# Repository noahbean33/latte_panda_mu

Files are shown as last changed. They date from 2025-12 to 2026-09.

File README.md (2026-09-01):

# LattePanda Mu Carrier Board

A custom 4-layer carrier board for the **LattePanda Mu** x86 compute module (Intel N100 / N305), designed in KiCad. The module supplies the CPU, RAM and storage; this board turns its 260-pin edge connector into real-world I/O with Gigabit Ethernet, HDMI, USB 2.0/3.0, two M.2 slots, GPIO/I²C/UART headers, PWM fan control, and a dual-input power supply.

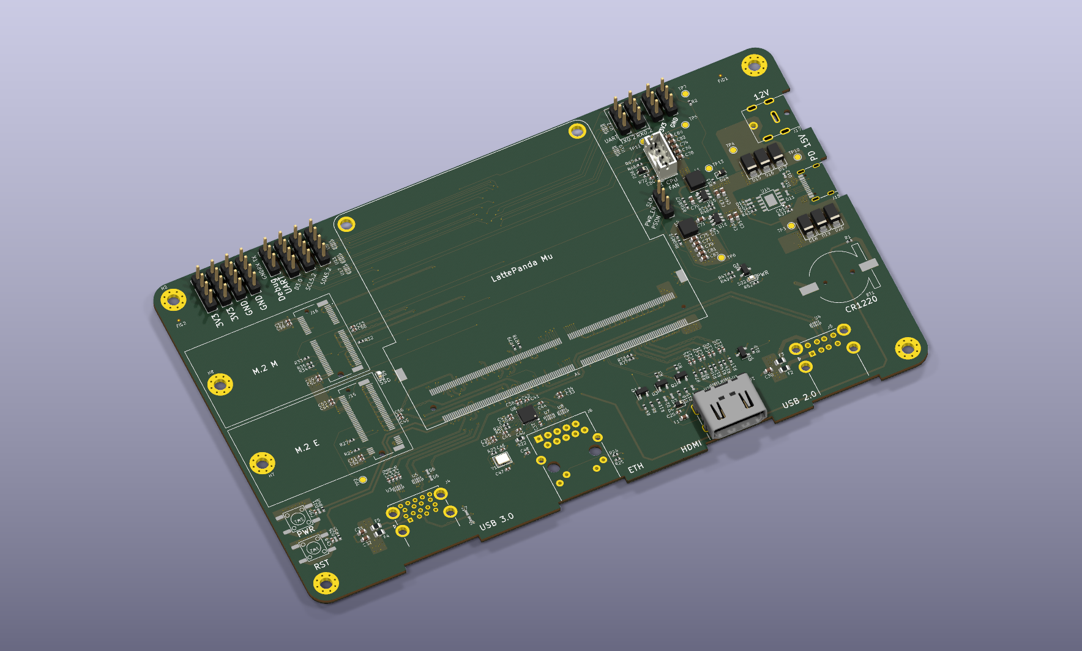
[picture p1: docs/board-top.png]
Top view of the carrier board


*3D render from the current KiCad source*

---

## Board at a glance

| | |
|---|---|
| **Outline** | 170.1 × 100.1 mm, 8 mounting holes (M3 + M2), 2 fiducials |
| **Stackup** | 4 layers — `F.Cu` / `In1.GND` / `In2.PWR` / `B.Cu`, 1.606 mm, FR4 εr 4.5, impedance-controlled |
| **Power in** | 12 V barrel jack **or** USB-C PD (CH224K negotiates 15 V) — diode-ORed onto a common `VDC` rail |
| **Rails** | `VDC` → 2× LM2734X buck → **+5V**, **+3V3**; **+1V0** local to the Ethernet PHY; **+BATT** from a CR1220 for the module RTC |
| **Ethernet** | RTL8111H-CG GbE controller on a PCIe x1 link, RJ45 with integrated magnetics |
| **Display** | HDMI Type-A, driven from the module's `DDI_B` port |
| **USB** | 2× USB 3.0 Type-A (stacked), 2× USB 2.0 Type-A (stacked), 1× USB-C (**power only**) |
| **M.2** | M-key (PCIe x1, NVMe) + E-key (PCIe x1 + USB 2.0, Wi-Fi/BT) |
| **Expansion** | PCIe x4 slot — fully designed, **not populated** in this revision |
| **Misc** | 4-pin PWM/tach fan header, power + reset buttons, debug UART, 13 test points (10 populated) |
| **Size of the job** | 217 placed footprints, 354 nets, 680 vias, 9 hierarchical sheets |

Full parts list: [`LattePandaMu_carrier_custom.csv`](LattePandaMu_carrier_custom.csv).

---

## Where the high-speed lanes go

| Module resource | Spent on | Notes |
|---|---|---|
| `HSIO_0` TX/RX | USB 3.0 port 1 SuperSpeed | TX AC-coupled (C26/C27) |
| `HSIO_1` TX/RX | USB 3.0 port 2 SuperSpeed | TX AC-coupled (C28/C29) |
| `HSIO_2` + `REFCLK0` | M.2 **M**-key — PCIe x1 | TX AC-coupled (C49/C50) |
| `HSIO_3` + `REFCLK3` | M.2 **E**-key — PCIe x1 | TX AC-coupled (C55/C56) |
| Dedicated GbE PCIe pair + clock | RTL8111H | AC-coupled (C38/C39/C42/C43) |
| `HSIO_8` – `HSIO_11` | *reserved* for the PCIe x4 slot | currently unrouted (slot is DNP) |
| `DDI_B_TX0..3` | HDMI TMDS | AC-coupled, ESD arrays U1/U2 |
| `USB2_P1/2/3/5` | 4× USB Type-A ports | |
| `USB2_P7` | M.2 E-key | Bluetooth on a combo card |
| `USB2_P4/6/8` | unused | |

AC coupling appears on **TX pairs only** — the far-end receiver provides its own caps, per PCIe and USB 3.0 convention.

---

## Schematic hierarchy

| Sheet | File | Contents |
|---|---|---|
| LattePanda Module | [`LattePanda_Module.kicad_sch`](LattePanda_Module.kicad_sch) | 260-pin module connector and all lane fan-out |
| Power Supply | [`psu.kicad_sch`](psu.kicad_sch) | DC jack, USB-C PD (CH224K), ORing, 2× buck, power sequencing |
| Gigabit Ethernet | [`ethernet.kicad_sch`](ethernet.kicad_sch) | RTL8111H, 25 MHz crystal, MDI pairs, RJ45 |
| HDMI | [`hdmi.kicad_sch`](hdmi.kicad_sch) | DDI_B → TMDS, ESD protection, fused +5 V |
| USB 2.0 & 3.0 | [`usb_2_3.kicad_sch`](usb_2_3.kicad_sch) | Stacked A-connectors, per-port fusing, ESD |
| M.2 M Key | [`m2_em_key.kicad_sch`](m2_em_key.kicad_sch) | Both the M-key and E-key sockets |
| PCIe x4 | [`pciex4.kicad_sch`](pciex4.kicad_sch) | x4 slot + AC caps — all DNP |
| GPIO | [`gpio.kicad_sch`](gpio.kicad_sch) | 4× I²C, 3× UART, 4× GPP headers |
| Fan | [`fan.kicad_sch`](fan.kicad_sch) | 4-pin PWM fan header and drive |

---

## Design rules

Net classes are pattern-assigned in the project file, so a net gets the right geometry from its name:

| Class | Applies to | Track / diff-pair geometry |
|---|---|---|
| `100Ω` | `*MDI*` (Ethernet magnetics side) | 0.144 mm width / 0.100 mm gap |
| `90Ω` | USB 2.0/3.0, PCIe, HSIO, TMDS, REFCLK | 0.199 mm width / 0.099 mm gap |
| `PWR` | `*+*V*` rails | 0.3 mm track, 0.2 mm clearance |
| `Default` | everything else | 0.15 mm track |

Board minimums: 0.14 mm track, 0.2 mm via / 0.2 mm hole, 0.1 mm annular ring, 0.2 mm copper-to-edge.

---

## Repository layout

```
.
├── LattePandaMu_carrier_custom.kicad_pro   # open this in KiCad
├── LattePandaMu_carrier_custom.kicad_pcb   # 4-layer layout
├── LattePandaMu_carrier_custom.kicad_sch   # root hierarchical schematic
├── LattePandaMu_carrier_custom.kicad_dru   # custom design rules
├── LattePandaMu_carrier_custom.csv         # BOM export
├── *.kicad_sch                             # sub-sheets (table above)
├── sym-lib-table / fp-lib-table            # project-scoped, ${KIPRJMOD}-relative
├── Libraries/                              # custom symbols and footprints
├── Assembly/                               # pick-and-place (top / bottom)
├── docs/                                   # renders and documentation images
```

---

## Getting started

1. Install **KiCad 10 or newer** <https://www.kicad.org/download/>.
2. Clone the repository:
   ```bash
   git clone https://github.com/noahbean33/latte_panda_mu.git
   ```
3. Open `LattePandaMu_carrier_custom.kicad_pro`. The library tables are `${KIPRJMOD}`-relative, so `Libraries/` is picked up with no global install.
4. Descend into sub-sheets from the root schematic; open the PCB editor for the layout.

Re-run the checks yourself:

```bash
kicad-cli sch erc --format json -o erc.json LattePandaMu_carrier_custom.kicad_sch
```

```bash
kicad-cli pcb drc --format json -o drc.json LattePandaMu_carrier_custom.kicad_pcb
```

---

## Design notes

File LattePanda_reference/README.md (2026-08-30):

# LattePanda Mu Carrier Development Resources

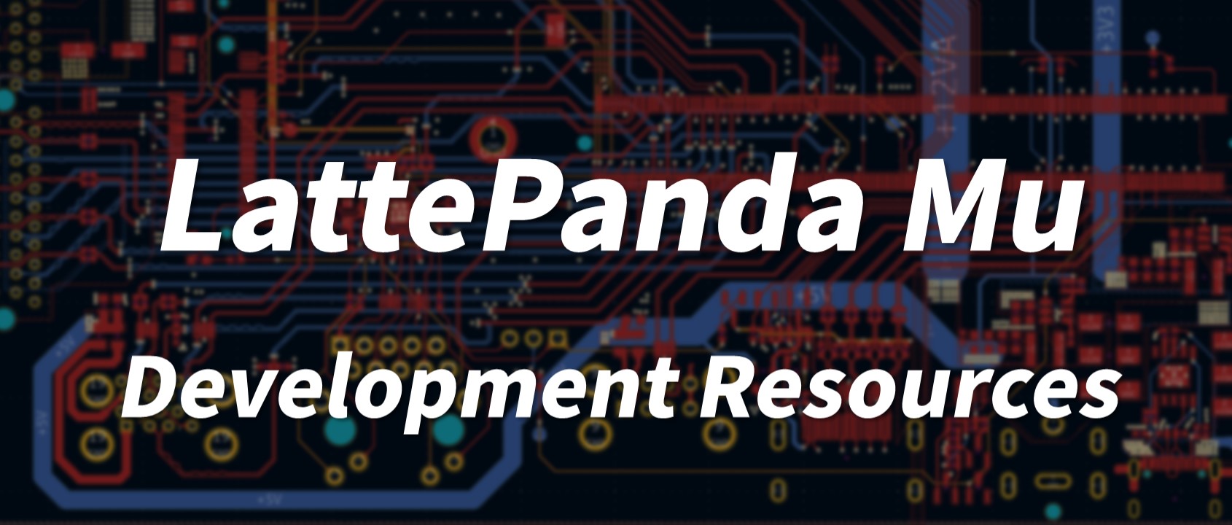
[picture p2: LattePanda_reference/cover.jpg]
cover


Welcome to the repository of development resources for the LattePanda Mu. With its extensive array of interfaces, you can craft your very own carrier board. While we have provided several reference designs to spark your creativity, a myriad of exciting possibilities awaits your discovery. This repository will be continuously updated to support the development of your personalized carrier board solutions.

## Documentation

- [**LattePanda Mu Compute Module User Guide**](https://docs.lattepanda.com/content/mu_edition/introduction/)

- [**Carrier Board Hardware Design Guide**](https://docs.lattepanda.com/content/mu_edition/design_guide_foreword/)

- [**Carrier Board User Guide**](https://docs.lattepanda.com/content/mu_edition/lite_carrier/)

- [**LattePanda Website**](https://www.lattepanda.com/)

- [**Join our Discord**](https://discord.gg/RkSvc9g7eU)

## Resource Directory

- **Electricals**: This includes pin descriptions, symbols and footprint libraries, project templates, and example projects.

- **Mechanicals**: This section provides dimensional drawings and 3D models of the LattePanda Mu, its heatsink, and other accessories.

- **Software**: BIOS, firmware, drivers, and other related software resources.

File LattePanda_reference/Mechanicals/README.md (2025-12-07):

# Model Files

Models of LattePanda Mu and related accessories for structural design use.

The STEP format models are large in size, hence they are compressed using 7-Zip. Please use [7-Zip](https://www.7-zip.org/) or another compatible software to extract the `.7z` files before use.

## Files

- [**LattePanda_Mu_Dimension_Drawing.pdf**](./LattePanda_Mu_Dimension_Drawing.pdf): LattePanda Mu Dimensional Drawing, PDF format

- [**LattePanda_Mu_Dimension_Drawing.dxf**](./LattePanda_Mu_Dimension_Drawing.dxf): LattePanda Mu Dimensional Drawing, DXF format

- [**LattePanda_Mu.step.7z**](./LattePanda_Mu.step.7z): Contains only the basic model of LattePanda Mu.

- [**LattePanda_Mu_H8.0_Horizontal.step.7z**](./LattePanda_Mu_H8.0_Horizontal.step.7z): Includes the model of LattePanda Mu and the H8.0 horizontal connector, which is the standard mounting method for LattePanda Mu, and can be used directly in PCB design as an enclosure model.

- [**LattePanda_Mu_H4.0_Horizontal.step.7z**](./LattePanda_Mu_H4.0_Horizontal.step.7z): Includes the model of LattePanda Mu and the H4.0 horizontal connector, and can be used directly in PCB design as an enclosure model.

- [**FIT0982-Thin-Heatsink.step.7z**](./FIT0982-Thin-Heatsink.step.7z): Thin heatsink only, without Mu.

- [**FIT0989-Fanless-Heatsink.step.7z**](./FIT0989-Fanless-Heatsink.step.7z): Fanless heatsink only, without Mu.

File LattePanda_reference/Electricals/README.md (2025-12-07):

# Electronic Design Resources

## Files

- Examples: Sample projects

- Libraries: Symbol and footprint libraries for LattePanda Mu

- Pinouts: All pin definitions for LattePanda Mu

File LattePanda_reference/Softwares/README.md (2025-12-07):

# Software Resources

Within this repository, you will find a range of software resources specifically related to the LattePanda Mu, including BIOS updates, firmware, and a variety of drivers.

Please be aware that this repository is dedicated to providing materials relevant to the LattePanda Mu. For firmware and drivers related to expansion carrier boards, refer to the respective carrier board documentation pages for more details.

## Resource Categories

- **BIOS**: Contains stable and beta BIOS updates officially supported, as well as related tools.

- **Drivers**: Drivers and related descriptions.

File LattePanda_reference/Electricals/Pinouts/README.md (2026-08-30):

# Pinouts

All pin definitions for LattePanda Mu(N100/N305 Processor)

⚠️ Note:  
Due to the large number of functionally multiplexing pins, you should check the [BIOS functionality documentation](../../Softwares/BIOS/README.md) before starting your design. Do not design directly from the pin definition documentation here.

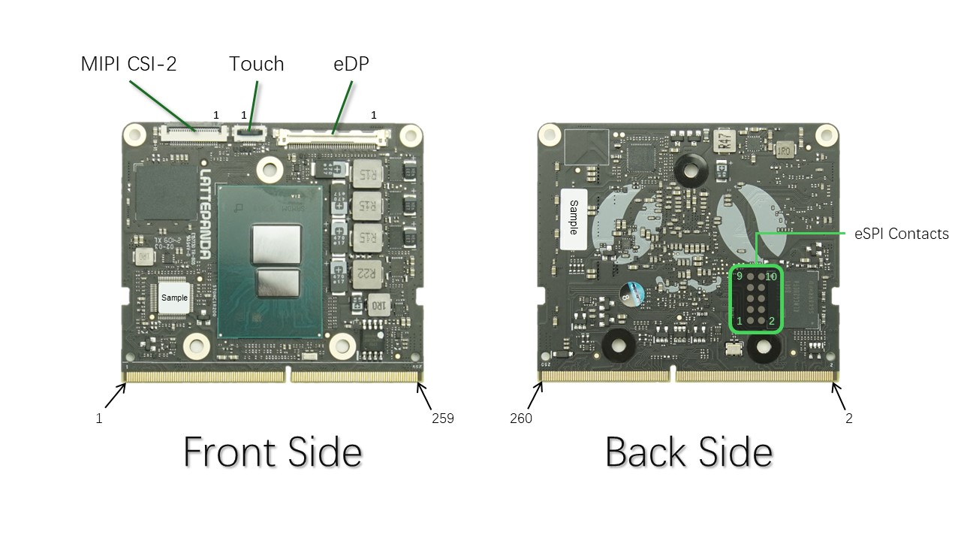
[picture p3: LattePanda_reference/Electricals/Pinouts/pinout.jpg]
pinout


## eDP

I-PEX 20455-040E

| Number | Name | Type | Description | Note |
|---|---|:----:|---|---|
| 1 | NC | | | |
| 2 | GND | | | |
| 3 | DDIA_TX3- | O | Lane 3 (-) | |
| 4 | DDIA_TX3+ | O | Lane 3 (+) | |
| 5 | GND | | | |
| 6 | DDIA_TX2- | O | Lane 2 (-) | |
| 7 | DDIA_TX2+ | O | Lane 2 (+) | |
| 8 | GND | | | |
| 9 | DDIA_TX1- | O | Lane 1 (-) | |
| 10 | DDIA_TX1+ | O | Lane 1 (+) | |
| 11 | GND | | | |
| 12 | DDIA_TX0- | O | Lane 0 (-) | |
| 13 | DDIA_TX0+ | O | Lane 0 (+) | |
| 14 | GND | | | |
| 15 | DDIA_AUX+ | O | Auxiliary channel (+) | |
| 16 | DDIA_AUX- | O | Auxiliary channel (-) | |
| 17 | GND | | | |
| 18 | LCD_VCC | | LCD Power Supplies | |
| 19 | LCD_VCC | | LCD Power Supplies | |
| 20 | LCD_VCC | | LCD Power Supplies | |
| 21 | LCD_VCC | | LCD Power Supplies | |
| 22 | Selftest  | O | Default Grounding | |
| 23 | GND | | | |
| 24 | GND | | | |
| 25 | GND | | | |
| 26 | GND | | | |
| 27 | HPD | I | Plug Detection | SoC GPP_E14 |
| 28 | GND | | | |
| 29 | GND | | | |
| 30 | GND | | | |
| 31 | GND | | | |
| 32 | BL_EN | O | Backlight enable | SoC eDP_BKLTEN  |
| 33 | BL_PWM | O | Backlight PWM dimming | SoC eDP_BKLTCTL |
| 34 | NC | | | |
| 35 | NC | | | |
| 36 | BL_PWR | | Backlight Power Supplies | |
| 37 | BL_PWR | | Backlight Power Supplies | |
| 38 | BL_PWR | | Backlight Power Supplies | |
| 39 | BL_PWR | | Backlight Power Supplies | |
| 40 | NC | | | |

- **LCD_VCC**: +3.3V
- **BL_PWR**: Same as LattePanda Mu input voltage
- **Selftest**: Factory test pin, ground by default

## Touch

Clamshell 6P 0.5mm FFC/FPC Connector

| Number | Name | Type | Description | Note |
|---|---|:----:|---|---|
| 1 | I2C0_SCL | O | I2C Bus | SoC GPP_H5  |
| 2 | I2C0_SDA | I/O  | I2C Bus | SoC GPP_H4  |
| 3 | GND | | | |
| 4 | TOUCH_RST# | O | Touch panel reset | SoC GPP_E13 |
| 5 | TOUCH_INT  | I | Touch event interrupt | SoC GPP_E17 |
| 6 | +3.3V | | Touch panel power | |

## MIPI CSI-2

Clamshell 22P 0.5mm FFC/FPC Connector

| Number | Name | Type | Description | Note |
|---|---|:----:|---|---|
| 1 | GND | | | |
| 2 | CSI_B_D0- | I | MIPI Data Lane 0  | |
| 3 | CSI_B_D0+ | I | MIPI Data Lane 0  | |
| 4 | GND | | | |
| 5 | CSI_B_D1- | I | MIPI Data Lane 1  | |
| 6 | CSI_B_D1+ | I | MIPI Data Lane 1  | |
| 7 | GND | | | |
| 8 | CSI_B_CK- | I | MIPI Clock | |
| 9 | CSI_B_CK+ | I | MIPI Clock | |
| 10 | GND | | | |
| 11 | CSI_B_D2- | I | MIPI Data Lane 2  | |
| 12 | CSI_B_D2+ | I | MIPI Data Lane 2  | |
| 13 | GND | | | |
| 14 | CSI_B_D3- | I | MIPI Data Lane 3  | |
| 15 | CSI_B_D3+ | I | MIPI Data Lane 3  | |
| 16 | GND | | | |
| 17 | CAM_RST | O | Camera reset | SoC GPP_A21 |
| 18 | CAM_MCLK  | O | Camera main clock | SoC GPP_D4  |
| 19 | GND | | | |
| 20 | I2C1_SCL  | O | I2C bus | SoC GPP_H7  |
| 21 | I2C1_SDA  | I/O  | I2C bus | SoC GPP_H6  |
| 22 | +3.3V | | Camera power | |

## eSPI Contacts

2.54mm Pitch Contacts

| Name | PIN | PIN | Name |
|---|:---:|:---:|---|
| ESPI_IO0 | 9 | 10  | GND |
| ESPI_IO1 | 7 | 8 | NC |
| ESPI_IO2 | 5 | 6 | ESPI_RESET# |
| ESPI_IO3 | 3 | 4 | ESPI_CS0# |
| ESPI_CLK | 1 | 2 | +1.8V |

Contacts on eSPI bus for SoC to communicate with SuperIO, can be used to connect diagnostic card (untested).

## Edge Connector(DDR4 SODIMM)

The edge_connector of LattePanda Mu is designed for DDR4 260P SODIMM. But this pin table is too long, so I put it in a separate .xlsx file.

- [LattePanda Mu Edge Connector Pinout](./LattePanda_Mu_Edge_Connector_Pinout.xlsx)

⚠️ Note:  
Due to the large number of functionally multiplexing pins, you should check the [BIOS functionality documentation](../../Softwares/BIOS/README.md) before starting your design. Do not design directly from the pin definition documentation here.

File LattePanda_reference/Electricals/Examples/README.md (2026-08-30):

# Sample Projects

LattePanda Mu carrier board sample projects for engineers' reference, designed with KiCAD. Please open with KiCAD version 9.0 or higher.

It's recommended to start your design with the *\[DFR1142\]Lite Carrier for LattePanda Mu(V2)*.

## Projects

- **\[DFR1141\]Full EVA Carrier for LattePanda Mu**: The evaluation carrier board that includes nearly all features of the LattePanda Mu, designed to ITX motherboard dimensions, suitable for professional developers.

- **\[DFR1142\]Lite Carrier for LattePanda Mu**: The lite carrier board that includes essential interfaces such as HDMI, USB, PCIe, designed to 3.5-inch embedded motherboard dimensions.

- **\[DFR1142\]Lite Carrier for LattePanda Mu(V2)**: The upgraded version of DFR1142 Lite Carrier. Optimized for evaluation use and small-batch deployment.
  - **Auto Power-On Support:** The system can boots automatically upon receiving power.
  - **New MX1.25-10P Connector:** Designed for compatibility with the DFR1247 LattePanda Smart UPS expansion board.
  - **Side-Mounted Buttons:** Power and Reset buttons have been changed to a side-mounted vertical design to accommodate protective cases better.
  - **External Control Headers:** Added pin headers for external power control and status indication.
  - **Sleep Indicator:** Added a dedicated LED for sleep mode status.
  - **BIOS Flash Chip Footprint:** Added a footprint for a carrier board BIOS flash chip (not soldered by default) for advanced customization.

- **\[DFR1144\]GPU Carrier for LattePanda Mu**: The GPU carrier board features six video output ports, supports Type A/B MXM standard graphics cards, and adopts the 3.5-inch embedded motherboard form factor. It is suitable for local AI inference or multi-screen display matrix applications.

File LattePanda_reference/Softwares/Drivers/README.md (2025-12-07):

# Drivers

This repository contains only the LattePanda Mu drivers. For drivers related to the carrier board, please refer to the carrier board documentation.

## Windows 10/11

After installing Windows, the system will automatically connect to the internet to download driver updates. If it is unable to access the Windows Update service, or if there are missing drivers after the automatic updates, you can download the offline driver package here.

| Name | Version | Size | Download |
|---|---|---|---|
| Intel Chipset Driver | 10.1.19376.8374 | 2.72 MB | [⬇️](./Chipset_10.1.19376.8374.zip) |
| Intel Iris Xe Graphics Driver | Latest | N/A | [⬇️](https://www.intel.com/content/www/us/en/download/785597/)[^1] |
| intel Serial IO Driver | 30.100.2229.4 | 353 KB  | [⬇️](./SerialIO_30.100.2229.4.zip) |
| intel HID Event Filter Driver | 2.2.1.386 | 46.6 KB | [⬇️](./HID_2.2.1.386.zip) |
| Intel Management Engine Interface Driver | 2306.4.10.0 | 20.5 MB | [⬇️](./MEI_2306.4.10.0.zip) |
| Intel GNA Scoring Accelerator Driver | 03.00.00.1457 | 54 KB | [⬇️](./GNA_03.00.00.1457.zip) |
| Intel Integrated Sensor Solution Driver | 3.1.0.4589 | 2.73 MB | [⬇️](./ISH_3.1.0.4589.zip) |
| TouchPanel Driver | 1.3.2.0 | 67.5 KB | [⬇️](./TouchPanel_1.3.2.0.zip) |

[^1]: Download from intel official website

## Linux

Linux drivers are generally provided by the distribution through kernel and kernel module updates. Please use a newer kernel version to ensure full driver support.

- Minimum kernel version: 5.18
- Recommended kernel version: 6.1 or later

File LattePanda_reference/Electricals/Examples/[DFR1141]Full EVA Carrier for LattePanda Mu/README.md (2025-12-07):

# \[DFR1141\]Full EVA Carrier for LattePanda Mu

Currently, only a **preview version** of the schematic and Gerber files are available for reference.

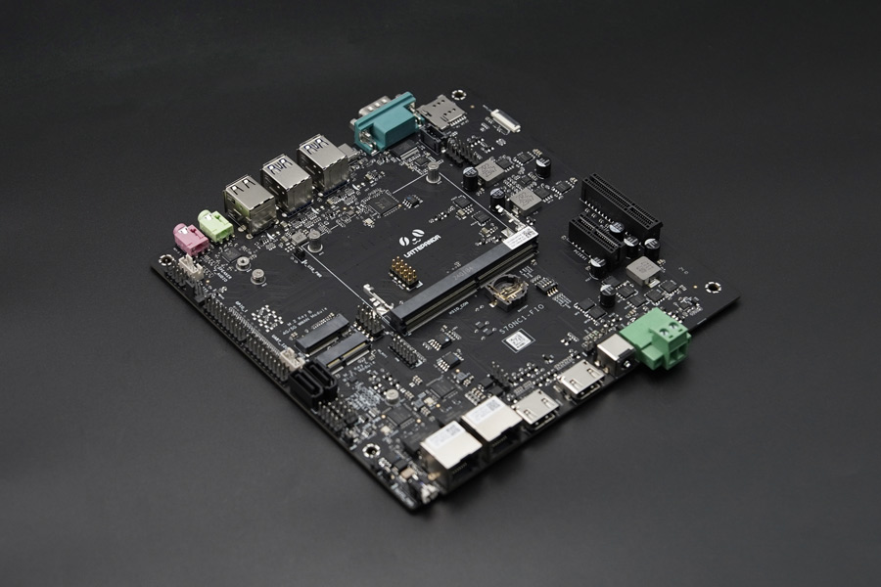
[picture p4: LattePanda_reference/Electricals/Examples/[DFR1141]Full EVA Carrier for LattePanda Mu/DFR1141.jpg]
DFR1141


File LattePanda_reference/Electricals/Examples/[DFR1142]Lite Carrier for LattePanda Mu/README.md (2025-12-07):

# DFR1142 Lite Carrier for LattePanda Mu

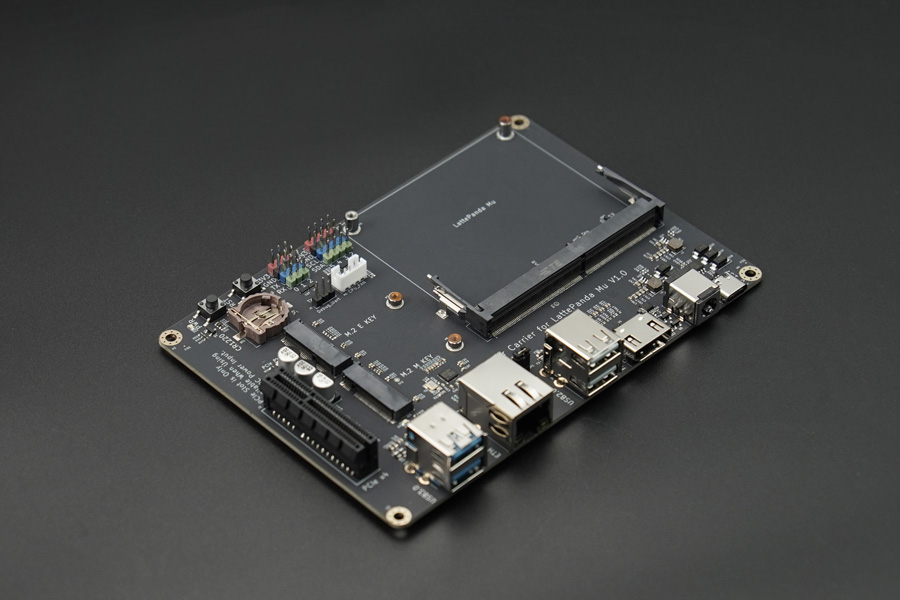
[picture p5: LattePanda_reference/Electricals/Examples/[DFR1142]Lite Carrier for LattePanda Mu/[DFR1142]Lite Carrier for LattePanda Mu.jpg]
DFR1142


## Specification

### Power Input

- USB Type-C PD: 15V (Max 3A)
- DC 5.5x2.5mm: 12~20V (Max 10A)

### Internal Interfaces

- PCIe 3.0 x4 slot (only available when using 12V power supply)
- M.2 M Key 2230 (PCIe 3.0 x1)
- M.2 E Key 2230 (PCIe 3.0 x1, USB2.0)
- RTC battery socket (CR1220 3V)
- CPU fan socket
- Gravity-4P UART
- Gravity-4P I2C

### External Interfaces

- USB 3.2 10Gbps x2
- Gigabit Ethernet
- USB 2.0 x2
- HDMI 2.0

### Dimension

3.5 inches, 146mm×102mm

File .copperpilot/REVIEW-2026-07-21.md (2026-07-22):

# Design Review — LattePanda Mu Carrier Board

Date: 2026-07-21 | KiCad 10.0.3 | Board: 170.1 x 100.0 mm, 4-layer

## Method
- Ran `kicad-cli sch erc` and `kicad-cli pcb drc` (client-side).
- Inspected netlist connectivity for U14 (CH224K USB-PD), U6 (RTL8111H GbE PHY).
- Cross-referenced against README block map (9 sub-sheets).

## ERC Results: 0 errors, 36 warnings
All warnings are cosmetic, not connectivity bugs:
- 20x `lib_symbol_mismatch` / `lib_symbol_issues` — symbols edited locally diverge from library copies, and `A_HDJ_Library` path still points to the original author's absolute `/Volumes/T7/...` path (broken on this machine but harmless since KiCad falls back to the project-local `Libraries/` copy via `${KIPRJMOD}`... verify `sym-lib-table` uses the relative path, not the absolute one baked into individual symbol metadata).
- 16x `multiple_net_names` in `usb_2_3.kicad_sch` — hierarchical labels (`USB_2_P2-`) and local labels (`CON_USB3_D_N`) are tied to the same wire. Not an error, but confusing; KiCad silently prefers one name. Recommend removing the redundant label on each net for clarity.

## DRC Results: 4 errors, 18 warnings
| Severity | Issue | Where |
|---|---|---|
| Error x4 | Courtyard overlaps between LattePanda Mu module (A1) and H5, H6 (mounting holes) and R78/R79 | Module footprint overlaps nearby mounting-hole and resistor courtyards |
| Warning | Silkscreen clipped by board edge | J18 (USB-C), J17 (DC jack), J6 |
| Warning | Silkscreen clipped by solder mask / overlap | A1 GND pad silkscreen, J17 pads, UART label vs rectangle |
| Warning | Footprint differs from library copy | U14, SW1/SW2, J17, A1 — same root cause as ERC symbol mismatches, now at footprint level |

**Priority fix:** the 4 courtyard-overlap errors around the LattePanda Mu module edge connector — confirm mechanical clearance is real or a false positive from an oversized courtyard on the module footprint; either way this should be resolved before fab to avoid assembly/probe issues near H5/H6/R78/R79.

## Connectivity Spot-Checks
- **U14 (CH224K USB-PD controller):** VBUS, CC1/CC2, D+/D- all wired to Type-C connector correctly. `CFG2`, `CFG3` (pads 2/3) and `PG` (pad 10) are unconnected. CFG pins select the negotiated voltage profile via strapping — confirm this floating condition matches the CH224K datasheet's intended default config (open = specific voltage set); if a fixed PD voltage is required, these need pull resistors.
- **U6 (RTL8111H GbE PHY):** Power (+1V0, +3V3), GND, and MDI0-3 differential pairs to the magnetics look correctly wired. `CLKREQB` (pad 12) and `LED0` (pad 27) are unconnected — both optional (PCIe clock request and status LED), not required for basic link-up but worth confirming against your GbE_PCIe_CLK usage on the PCIe sheet, since RTL8111H shares a PCIe reference clock with the PCIe x4 slot.
- Net analysis shows differential pairs are named consistently across sheets (`GbE_PCIe_CLK+/-`, `MDI0+/-` etc.) — hierarchical labeling is clean.

## What's Done Well
- Zero ERC errors and zero DRC unconnected-item errors — full netlist connectivity is intact across all 9 sub-sheets.
- Consistent hierarchical net naming for high-speed diff pairs (Ethernet MDI, PCIe clock, USB3 SS lanes).
- 4-layer stackup with internal power planes (In1.Cu/In2.Cu) appropriate for this rail count (+12V/+15V/+1V0/+3V3/+5V/+BATT).
- Power path protection ICs (D3V3XA4B10LP, multiple instances) placed on each I/O rail — good ESD/surge practice for connectors.

## Prioritized Fix List
1. **[High]** Resolve 4 courtyard-overlap DRC errors near the LattePanda Mu module connector (A1 vs H5/H6/R78/R79).
2. **[Medium]** Fix broken `A_HDJ_Library` absolute path reference in symbol library table so ERC stops flagging library issues on another machine/CI.
3. **[Medium]** Confirm CH224K (U14) CFG2/CFG3/PG floating pins are intentional per datasheet default-voltage strapping table.
4. **[Low]** Clean up redundant hierarchical/local label pairs in `usb_2_3.kicad_sch` (16 instances) for schematic clarity.
5. **[Low]** Address silkscreen-clipped-by-edge/mask warnings (J18, J17, J6, A1) — cosmetic/manufacturing polish only.
6. **[Low]** Sync footprint/symbol library copies to eliminate `lib_symbol_mismatch`/`lib_footprint_mismatch` warnings (U14, SW1/SW2, J17, A1).

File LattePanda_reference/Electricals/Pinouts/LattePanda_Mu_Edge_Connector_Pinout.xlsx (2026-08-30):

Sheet: Overview
Speed: Indicates the operating speed of the signal pin. "Low" denotes low-speed signals requiring only standard PCB routing. "High" denotes high-speed signals which mandate impedance matching in the PCB design.
IO Level: For multiplexed pins, the IO voltage level may vary depending on the configured function. This document specifies the maximum voltage level supported by the pin.
Note:
This document is applicable only to LattePanda Mu compute modules equipped with Intel N100 and N305 processors.
Due to the large number of pins that serve multiple functions, please consult the BIOS functionality documentation before beginning your design.
https://github.com/LattePandaTeam/LattePanda-Mu/tree/main/Softwares/BIOS
Pinout Description Page
https://github.com/LattePandaTeam/LattePanda-Mu/tree/main/Electricals/Pinouts

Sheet: Front
Pin | Signal Name | Direction | IO Level | Description | Speed | Notes
1 | PWR_SW# | I | 3.3V | System Power Switch | Low | Active LOW; Internally 10K Pulled Up
3 | RST_SW# | I | 3.3V | System Reset Switch | Low | Active LOW; Internally 10K Pulled Up
5 | PSON | O | 3.3V | System Power Supply Status | Low | Output HIGH only when S0(Working); 10K Pull-up to 3.3V (Weak Drive of HIGH output)
7 | SLP_S4 | O | 3.3V | System Status | Low | Output HIGH only when S0(Working) and S3(Sleeping)
9 | TSENSE | I | 3.3V | NTC Temperature Sensor | Low
11 | GND | PWR | 0V | Ground | /
13 | HSIO0_TX_P | O | 0.8V | HSIO0 TX Differential Pair | High | External AC Coupling Capacitor Required
15 | HSIO0_TX_N | O | 0.8V | HSIO0 TX Differential Pair | High | External AC Coupling Capacitor Required
17 | GND | PWR | 0V | Ground | /
19 | HSIO1_TX_P | O | 0.8V | HSIO1 TX Differential Pair | High | External AC Coupling Capacitor Required
21 | HSIO1_TX_N | O | 0.8V | HSIO1 TX Differential Pair | High | External AC Coupling Capacitor Required
23 | GND | PWR | 0V | Ground | /
25 | HSIO2_TX_P | O | 0.8V | HSIO2 TX Differential Pair | High | External AC Coupling Capacitor Required
27 | HSIO2_TX_N | O | 0.8V | HSIO2 TX Differential Pair | High | External AC Coupling Capacitor Required
29 | GND | PWR | 0V | Ground | /
31 | HSIO3_TX_P | O | 0.8V | HSIO3 TX Differential Pair | High | External AC Coupling Capacitor Required
33 | HSIO3_TX_N | O | 0.8V | HSIO3 TX Differential Pair | High | External AC Coupling Capacitor Required
35 | GND | PWR | 0V | Ground | /
37 | HSIO8_TX_P | O | 0.8V | HSIO8 TX Differential Pair | High | External AC Coupling Capacitor Required
39 | HSIO8_TX_N | O | 0.8V | HSIO8 TX Differential Pair | High | External AC Coupling Capacitor Required
41 | GND | PWR | 0V | Ground | /
43 | HSIO9_TX_P | O | 0.8V | HSIO9 TX Differential Pair | High | External AC Coupling Capacitor Required
45 | HSIO9_TX_N | O | 0.8V | HSIO9 TX Differential Pair | High | External AC Coupling Capacitor Required
47 | GND | PWR | 0V | Ground | /
49 | HSIO10_TX_P | O | 0.8V | HSIO10 TX Differential Pair | High | External AC Coupling Capacitor Required
51 | HSIO10_TX_N | O | 0.8V | HSIO10 TX Differential Pair | High | External AC Coupling Capacitor Required
53 | GND | PWR | 0V | Ground | /
55 | HSIO11_TX_P | O | 0.8V | HSIO11 TX Differential Pair | High | External AC Coupling Capacitor Required
57 | HSIO11_TX_N | O | 0.8V | HSIO11 TX Differential Pair | High | External AC Coupling Capacitor Required
59 | GND | PWR | 0V | Ground | /
61 | HSIO6_TX_P | O | 0.8V | HSIO6 TX Differential Pair | High | External AC Coupling Capacitor Required
63 | HSIO6_TX_N | O | 0.8V | HSIO6 TX Differential Pair | High | External AC Coupling Capacitor Required
65 | GND | PWR | 0V | Ground | /
67 | USB2_P1_N | I/O | 3.3V | USB 2.0 Port 1 Differential Pair | High
69 | USB2_P1_P | I/O | 3.3V | USB 2.0 Port 1 Differential Pair | High
71 | GND | PWR | 0V | Ground | /
73 | USB2_P2_N | I/O | 3.3V | USB 2.0 Port 2 Differential Pair | High
75 | USB2_P2_P | I/O | 3.3V | USB 2.0 Port 2 Differential Pair | High
77 | GND | PWR | 0V | Ground | /
79 | USB2_P3_N | I/O | 3.3V | USB 2.0 Port 3 Differential Pair | High
81 | USB2_P3_P | I/O | 3.3V | USB 2.0 Port 3 Differential Pair | High
83 | GND | PWR | 0V | Ground | /
85 | REFCLK0_P | O | 0.8V | PCIe Reference Clock 0 Differential Pair | High | 100MHz
87 | REFCLK0_N | O | 0.8V | PCIe Reference Clock 0 Differential Pair | High | 100MHz
89 | GND | PWR | 0V | Ground | /
91 | REFCLK1_P | O | 0.8V | PCIe Reference Clock 1 Differential Pair | High | 100MHz
93 | REFCLK1_N | O | 0.8V | PCIe Reference Clock 1 Differential Pair | High | 100MHz
95 | GND | PWR | 0V | Ground | /
97 | REFCLK2_P | O | 0.8V | PCIe Reference Clock 2 Differential Pair | High | 100MHz
99 | REFCLK2_N | O | 0.8V | PCIe Reference Clock 2 Differential Pair | High | 100MHz
101 | GND | PWR | 0V | Ground | /
103 | PCIE_WAKE# | I | 3.3V | PCIe Wake Request | Low | Pulled LOW to Wake System; Internally 1K Pulled Up
105 | PLT_RST# | O | 3.3V | Platform Reset for PCIe | Low | Output LOW to Reset PCIe Device
107 | GND | PWR | 0V | Ground | /
109 | USB2_P5_N | I/O | 3.3V | USB 2.0 Port 5 Differential Pair | High
111 | USB2_P5_P | I/O | 3.3V | USB 2.0 Port 5 Differential Pair | High
113 | GND | PWR | 0V | Ground | /
115 | VBAT | PWR | 3.0V | RTC Battery Input | /
117 | PROCHOT# | I | 3.3V | (TCC) Overheat Protect | Low | Active LOW; Internally 10K Pulled Up
119 | GPP_E0 | I/O | 3.3V | GPIO | Low | BIOS Default Function:WWAN_PWR_EN
121 | GPP_A12 | I/O | 3.3V | GPIO | Low | BIOS Default Function:CAM_PWR_EN
123 | SATA_LED# | O | 3.3V | SATA HDD Activity Status | Low | Active LOW
125 | PMCALERT# | I | 3.3V | USB Type-C PD Controller / Re-timer Alert | Low | Active LOW; Internally 10K Pulled Up
127 | TPM_IRQ | I | 3.3V | Discrete TPM Interrupt | Low
129 | USB_OC# | I | 3.3V | USB Over Current | Low | Active LOW; Internally 10K Pulled Up
131 | SUSCLK | O | 3.3V | Suspend Clock | Low | 32.768KHz
133 | BIOS_SEL | I | 3.3V | BIOS ROM Select | Low | Internally 100K Pulled Up； HIGH: Integrated ROM; LOW: Carrier ROM
135 | GND | PWR | 0V | Ground | /
137 | UART0_RXD / GPP_H10 | I/O | 3.3V | SoC UART0 RX / GPIO | Low | BIOS Default Function: UART
139 | UART0_TXD / GPP_H11 | I/O | 3.3V | SoC UART0 TX / GPIO | Low | BIOS Default Function: UART
141 | UART1_RXD / GPP_D17 | I/O | 3.3V | SoC UART1 RX / GPIO | Low | BIOS Default Function: UART
143 | UART1_TXD / GPP_D18 | I/O | 3.3V | SoC UART1 TX / GPIO | Low | BIOS Default Function: UART
KEY
145 | SML1_DATA | I/O | 3.3V | SMLink1 Data | Low | Internally 2.2K Pulled Up
147 | SML1_CLK | O | 3.3V | SMLink1 Clock | Low | Internally 2.2K Pulled Up
149 | SML1_ALERT# | I | 3.3V | SMLink1 Alert | Low | Active LOW
151 | GND | PWR | 0V | Ground | /
153 | SPI_IO3 | I/O | 3.3V | SPI Bus for BIOS and dTPM | Low
155 | SPI_CLK | O | 3.3V | SPI Bus for BIOS and dTPM | Low
157 | SPI_CS2# | O | 3.3V | SPI Chip Select for dTPM | Low
159 | SPI_MOSI/SPI_IO0 | I/O | 3.3V | SPI Bus for BIOS and dTPM | Low
161 | SPI_IO2 | I/O | 3.3V | SPI Bus for BIOS and dTPM | Low
163 | SPI_MISO/SPI_IO1 | I/O | 3.3V | SPI Bus for BIOS and dTPM | Low
165 | SPI_CS# | O | 3.3V | SPI Chip Select for BIOS ROM | Low
167 | GND | PWR | 0V | Ground | /
169 | DDIB_CTRL_DATA | I/O | 3.3V | DDIB Control Data | Low | Internally 2.2K Pulled Up
171 | DDIB_CTRL_CLK | O | 3.3V | DDIB Control Clock | Low | Internally 2.2K Pulled Up
173 | TCP1_CTRL_DATA | I/O | 3.3V | TCP1 Control Data | Low | Internally 2.2K Pulled Up
175 | TCP1_CTRL_CLK | O | 3.3V | TCP1 Control Clock | Low | Internally 2.2K Pulled Up
177 | TCP0_CTRL_DATA | I/O | 3.3V | TCP0 Control Data | Low | Internally 2.2K Pulled Up
179 | TCP0_CTRL_CLK | O | 3.3V | TCP0 Control Clock | Low | Internally 2.2K Pulled Up
181 | GND | PWR | 0V | Ground | /
183 | DDIB_HPD | I | 3.3V | DDIB Hot Plug Detect | Low
185 | TCP1_HPD | I | 3.3V | TCP1 Hot Plug Detect | Low
187 | TCP0_HPD | I | 3.3V | TCP0 Hot Plug Detect | Low
189 | GND | PWR | 0V | Ground | /
191 | DDIB_AUX_N | I/O | 3.3V | DDIB DP Auxiliary Channel | Low
193 | DDIB_AUX_P | I/O | 3.3V | DDIB DP Auxiliary Channel | Low
195 | GND | PWR | 0V | Ground | /
197 | DDIB_TX3_N | O | 3.3V | DDIB DP Lane 3 / HDMI TMDS Clock | High | External AC Coupling Capacitor Required
199 | DDIB_TX3_P | O | 3.3V | DDIB DP Lane 3 / HDMI TMDS Clock | High | External AC Coupling Capacitor Required
201 | GND | PWR | 0V | Ground | /
203 | DDIB_TX2_N | O | 3.3V | DDIB DP Lane 2 / HDMI TMDS Data0 | High | External AC Coupling Capacitor Required
205 | DDIB_TX2_P | O | 3.3V | DDIB DP Lane 2 / HDMI TMDS Data0 | High | External AC Coupling Capacitor Required
207 | GND | PWR | 0V | Ground | /
209 | DDIB_TX1_N | O | 3.3V | DDIB DP Lane 1 / HDMI TMDS Data1 | High | External AC Coupling Capacitor Required
211 | DDIB_TX1_P | O | 3.3V | DDIB DP Lane 1 / HDMI TMDS Data1 | High | External AC Coupling Capacitor Required
213 | GND | PWR | 0V | Ground | /
215 | DDIB_TX0_N | O | 3.3V | DDIB DP Lane 0 / HDMI TMDS Data2 | High | External AC Coupling Capacitor Required
217 | DDIB_TX0_P | O | 3.3V | DDIB DP Lane 0 / HDMI TMDS Data2 | High | External AC Coupling Capacitor Required
219 | GND | PWR | 0V | Ground | /
221 | TCP0_AUX_N | I/O | 3.3V | TCP0 DP Auxiliary Channel | Low
223 | TCP0_AUX_P | I/O | 3.3V | TCP0 DP Auxiliary Channel | Low
225 | GND | PWR | 0V | Ground | /
227 | TCP0_TXRX1_N | I/O | 3.3V | TCP0 DP Lane 3 / HDMI TMDS Clock / Type C RX Data Lane 2 | High | External AC Coupling Capacitor Required
229 | TCP0_TXRX1_P | I/O | 3.3V | TCP0 DP Lane 3 / HDMI TMDS Clock / Type C RX Data Lane 2 | High | External AC Coupling Capacitor Required
231 | GND | PWR | 0V | Ground | /
233 | TCP0_TX1_N | O | 3.3V | TCP0 DP Lane 2 / HDMI TMDS Data0 / Type C TX Data Lane 2 | High | External AC Coupling Capacitor Required
235 | TCP0_TX1_P | O | 3.3V | TCP0 DP Lane 2 / HDMI TMDS Data0 / Type C TX Data Lane 2 | High | External AC Coupling Capacitor Required
237 | GND | PWR | 0V | Ground | /
239 | TCP0_TXRX0_N | I/O | 3.3V | TCP0 DP Lane 1 / HDMI TMDS Data1 / Type C RX Data Lane 1 | High | External AC Coupling Capacitor Required
241 | TCP0_TXRX0_P | I/O | 3.3V | TCP0 DP Lane 1 / HDMI TMDS Data1 / Type C RX Data Lane 1 | High | External AC Coupling Capacitor Required
243 | GND | PWR | 0V | Ground | /
245 | TCP0_TX0_N | O | 3.3V | TCP0 DP Lane 0 / HDMI TMDS Data2 / Type C TX Data Lane 1 | High | External AC Coupling Capacitor Required
247 | TCP0_TX0_P | O | 3.3V | TCP0 DP Lane 0 / HDMI TMDS Data2 / Type C TX Data Lane 1 | High | External AC Coupling Capacitor Required
249 | GND | PWR | 0V | Ground | /
251 | VIN | PWR | 9V ~ 20V | Main Power Input | /
253 | VIN | PWR | 9V ~ 20V | Main Power Input | /
255 | VIN | PWR | 9V ~ 20V | Main Power Input | /
257 | VIN | PWR | 9V ~ 20V | Main Power Input | /
259 | VIN | PWR | 9V ~ 20V | Main Power Input | /
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

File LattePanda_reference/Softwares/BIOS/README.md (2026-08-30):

# BIOS

This repository includes official releases and beta versions of BIOS for various branches, as well as related tools.

- ⚠ Generally, you should only upgrade the BIOS of the same branch. Cross-branch upgrades should only be performed when testing different BIOS features.
- ⚠ Upgrading the BIOS across different branches will invalidate the Secure Boot keys.
- ⚠ Upgrading to the incorrect BIOS branch may result in some functions of the carrier board not working properly.

------

## Naming Rule

### New Naming Scheme (2025-12 and later)

**Format**
`S70NC1R200-[Memory]-[Version][-Variant].bin`

- **S70NC1R200**: Platform identifier (LattePanda Mu N100/N305)
- **Memory**:
  - `8G` = 8GB RAM
  - `16G` = 16GB RAM
- **Version**:
  - `A`, `B`, `C`... (incremented alphabetically for each new release)
- **Variant** (optional):
  - *(no suffix)* = Default (PCIe)
  - `SATA` = SATA branch

**Examples**

- `S70NC1R200-8G-A.bin` → 8GB, Default (PCIe)
- `S70NC1R200-16G-A-SATA.bin` → 16GB, SATA

**Notes**

- New scheme is simplified and user-oriented.
- **All subsequent updates will follow this naming convention.**

### Legacy Naming Scheme (2024 Initial Release)

**Format**
`LP-BS-S70NC1R200-[Rank]-[Version][-Variant].bin`

- **LP**: LattePanda
- **BS**: BIOS
- **S70NC1R200**: Platform identifier(LattePanda Mu N100/N305)
- **Rank**:
  - `SR` = Single Rank (corresponds to 8GB models)
  - `DR` = Dual Rank (corresponds to 16GB models)
- **Version**:
  - `A`, `B`
- **Variant**:
  - *(no suffix)* = Default (PCIe)
  - `SATA` = SATA branch

**Example**

- `LP-BS-S70NC1R200-SR-B.bin` → 8GB, Default (PCIe)

- `LP-BS-S70NC1R200-DR-B-SATA.bin` → 16GB, SATA

### Mapping: Legacy → New Naming

- `SR` → `8G`
- `DR` → `16G`

**Examples**

- `LP-BS-S70NC1R200-SR-B.bin` → `S70NC1R200-8G-A.bin` (newer)
- `LP-BS-S70NC1R200-DR-B-SATA.bin` → `S70NC1R200-16G-A-SATA.bin` (newer)

------

## Folder Description

- Beta: Beta version BIOS, not specific to any branch, intended for professional developers to assess new features.
- DFLT: Default version BIOS, which is the BIOS branch that comes pre-installed on the LattePanda Mu.
- SATA: A BIOS branch that provides SATA interface signal.
- Tools: Tools for BIOS maintenance.

------

## Release Timeline

```text
    2024-06/07                  2025-12                    2026-06
        │                          │                          |
        ●──────────────────────────●──────────────────────────●
        │                          │                          |
[Initial Release]           [Second Release]          [Current Recommended]
    DFLT,SATA                  DFLT,SATA                  DFLT,SATA 
```

For specific model compatibility and functional changes, please refer to the `BOS Release Notes` located in each branch's folder.

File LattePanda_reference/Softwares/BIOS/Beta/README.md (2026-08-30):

# Beta BIOS

- Beta BIOS may contain unforeseen issues and is recommended for professional developers to try out only.

- Unless specified otherwise, these will not be merged into the main branches (DFLT and SATA) by default.

## LP-BS-S70NC1R200-SR-20240410

Modified from **LP-BS-S70NC1R200-SR-A**, with IBECC option enabled for evaluating stability and performance differences.

**Suitable for:** LattePanda Mu N100 8GB

**Note:** The IBECC option has been integrated into the BIOS firmware of the main branches (DFLT and SATA).

## LP-BS-S70NC1R200-SR-DEBUG

Enable intel DCI debugging interface and UEFI log output for open source firmware developers

**Suitable for:** LattePanda Mu N100 8GB

## LP-BS-S70NC1R200-SR-TGPIO

TGPIO function is enabled. A precise 1pps pulse signal is continuously output at Pin 123 for time sensitive applications.

**Suitable for:** LattePanda Mu N100 8GB

## LP-BS-S70NC1R200-DR-B-TGPIO

TGPIO function is enabled. A precise 1pps pulse signal is continuously output at Pin 123 for time sensitive applications.

**Suitable for:** LattePanda Mu N100 16GB / N305 16GB

## S70NC1R200-8G-B-Windows-GPIO

This firmware introduces native support for GPIO and I2C interfaces under Windows operating systems. 

**Suitable for:** LattePanda Mu N100 8GB

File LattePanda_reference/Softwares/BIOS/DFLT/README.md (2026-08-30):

💡**Note:** The LattePanda Mu compute module is available in 8GB and 16GB memory versions. It is essential to select the correct BIOS firmware as described below.

### For LattePanda Mu N100 **8GB** RAM Model:

- LP-BS-S70NC1R200-SR-B
- S70NC1R200-8G-A
- S70NC1R200-8G-B **(Latest)**

### For LattePanda Mu N100 / N305 **16GB** RAM Model:

- LP-BS-S70NC1R200-DR-B
- S70NC1R200-16G-A
- S70NC1R200-16G-B **(Latest)**

---

# BIOS Release Notes

## [2026-06] Latest Release
### 📂 BIOS Files
| Variant  | Compatible Model | Filename | Build Date |
| :--- | :--- | :--- | --- |
| **PCIe** | LattePanda Mu N100 **8GB** | `S70NC1R200-8G-B.bin` | 2026/06/03 |
| **PCIe** | LattePanda Mu N100 / N305 **16GB** | `S70NC1R200-16G-B.bin` | 2026/06/03 |
| **SATA** | LattePanda Mu N100 **8GB** | `S70NC1R200-8G-B-SATA.bin`  | 2026/06/03 |
| **SATA** | LattePanda Mu N100 / N305 **16GB** | `S70NC1R200-16G-B-SATA.bin` | 2026/06/03 |

### 📝 Changelog
1. Fixed a security bypass where pressing Enter with an empty password allowed read-only BIOS access. 
2. Added support for controlling GPIO and I2C drivers directly within Windows. 

## [2025-12] Second Release
### 📂 BIOS Files
| Variant | Compatible Model | Filename | Build Date |
| :--- | :--- | :--- | ---- |
| **PCIe** | LattePanda Mu N100 **8GB** | `S70NC1R200-8G-A.bin` | 2025/12/19 |
| **PCIe** | LattePanda Mu N100 / N305 **16GB** | `S70NC1R200-16G-A.bin` | 2025/12/19 |
| **SATA** | LattePanda Mu N100 **8GB** | `S70NC1R200-8G-A-SATA.bin` | 2025/12/19 |
| **SATA** | LattePanda Mu N100 / N305 **16GB** | `S70NC1R200-16G-A-SATA.bin` | 2025/12/19 |

### 📝 Changelog
1. Added SMBIOS information.
2. Added information for eMMC, SATA, NVMe, etc. in the Main tab.
3. Unlocked PCIe Clock configuration menu.
4. Unlocked PCIe port ASPM configuration menu (Default: Disabled).
5. Added toggle options for TP (Touch Panel) and eDP display.
6. Added GPIO function support and configuration menu.
7. Enabled SpeedStep(TM) and RC6; changed Package C State Limit to Auto.
8. Added RTL8111H PXE boot support.
9. Fixed the issue of duplicate UART numbering in the OS.
10. Added Windows Recovery support (Requires customized OS).

---

## [2024-06/07] Initial Release
### 📂 BIOS Files
| Variant | Compatible Model | Filename | Build Date |
| :--- | :--- | :--- | ---- |
| **PCIe** | LattePanda Mu N100 **8GB** | `LP-BS-S70NC1R200-SR-B.bin` | 2024/07/08 |
| **PCIe** | LattePanda Mu N100 / N305 **16GB** | `LP-BS-S70NC1R200-DR-B.bin` | 2024/06/19 |
| **SATA** | LattePanda Mu N100 **8GB** | `LP-BS-S70NC1R200-SR-B-SATA.bin` | 2024/07/05 |
| **SATA** | LattePanda Mu N100 / N305 **16GB** | `LP-BS-S70NC1R200-DR-B-SATA.bin` | 2024/06/20 |

### 📝 Changelog
- Initial BIOS firmware release.

---

# DFLT Branch Introduction

Default factory BIOS interface configuration for LattePanda Mu.

## Interface Configuration

### Special Notes

- **USB2_P6**: Dedicated for USB Type-C, must be used in conjunction with a PD controller, **cannot be used as a standard USB port**.

### HSIO (High-Speed Input/Output)

- **HSIO0**: USB 3.2 10Gbps
- **HSIO1**: USB 3.2 10Gbps
- **HSIO2**: PCIe 3.0 x1
- **HSIO3**: PCIe 3.0 x1
- ==========
- **HSIO8**: PCIe 3.0 x4 (Lane 0)
- **HSIO9**: PCIe 3.0 x4 (Lane 1)
- **HSIO10**: PCIe 3.0 x4 (Lane 2)
- **HSIO11**: PCIe 3.0 x4 (Lane 3)
- ==========
- **HSIO6**: PCIe 3.0 x1

### DDI/TCP

- **DDIA**: eDP 1.4b (eDP interface on LattePanda Mu)

- **DDIB**: HDMI 2.0

- **TCP0**: HDMI 2.0

- **TCP1**: USB Type-C (requires external PD controller)

### GPIOs

- **I2C1**: Touch panel (touch connector on LattePanda Mu)
- **I2C2**: Communication with Type-C PD controller
- **GPP_B11**: Type-C PD controller PMCALERT\#
- **GPP_B14**: SATA HDD LED
- **GPP_D0**: WWAN_Power_Off
- **GPP_D1**: WWAN_Reset
- **GPP_D2**: Communication interrupt with Type-C PD controller

Other GPIOs not listed are not allocated specific functions.

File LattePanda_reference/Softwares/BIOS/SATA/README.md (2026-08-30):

💡**Note:** The LattePanda Mu compute module is available in 8GB and 16GB memory versions. It is essential to select the correct BIOS firmware as described below.

### For LattePanda Mu N100 **8GB** RAM Model:

- LP-BS-S70NC1R200-SR-B-SATA
- S70NC1R200-8G-A-SATA
- S70NC1R200-8G-B-SATA **(Latest)**

### For LattePanda Mu N100 / N305 **16GB** RAM Model:

- LP-BS-S70NC1R200-DR-B-SATA
- S70NC1R200-16G-A-SATA
- S70NC1R200-16G-B-SATA **(Latest)**

---

# BIOS Release Notes

## [2026-06] Latest Release
### 📂 BIOS Files
| Variant  | Compatible Model | Filename | Build Date |
| :--- | :--- | :--- | --- |
| **PCIe** | LattePanda Mu N100 **8GB** | `S70NC1R200-8G-B.bin` | 2026/06/03 |
| **PCIe** | LattePanda Mu N100 / N305 **16GB** | `S70NC1R200-16G-B.bin` | 2026/06/03 |
| **SATA** | LattePanda Mu N100 **8GB** | `S70NC1R200-8G-B-SATA.bin`  | 2026/06/03 |
| **SATA** | LattePanda Mu N100 / N305 **16GB** | `S70NC1R200-16G-B-SATA.bin` | 2026/06/03 |

### 📝 Changelog
1. Fixed a security bypass where pressing Enter with an empty password allowed read-only BIOS access. 
2. Added support for controlling GPIO and I2C drivers directly within Windows. 

## [2025-12] Second Release
### 📂 BIOS Files
| Variant | Compatible Model | Filename | Build Date |
| :--- | :--- | :--- | ---- |
| **PCIe** | LattePanda Mu N100 **8GB** | `S70NC1R200-8G-A.bin` | 2025/12/19 |
| **PCIe** | LattePanda Mu N100 / N305 **16GB** | `S70NC1R200-16G-A.bin` | 2025/12/19 |
| **SATA** | LattePanda Mu N100 **8GB** | `S70NC1R200-8G-A-SATA.bin` | 2025/12/19 |
| **SATA** | LattePanda Mu N100 / N305 **16GB** | `S70NC1R200-16G-A-SATA.bin` | 2025/12/19 |

### 📝 Changelog
1. Added SMBIOS information.
2. Added information for eMMC, SATA, NVMe, etc. in the Main tab.
3. Unlocked PCIe Clock configuration menu.
4. Unlocked PCIe port ASPM configuration menu (Default: Disabled).
5. Added toggle options for TP (Touch Panel) and eDP display.
6. Added GPIO function support and configuration menu.
7. Enabled SpeedStep(TM) and RC6; changed Package C State Limit to Auto.
8. Added RTL8111H PXE boot support.
9. Fixed the issue of duplicate UART numbering in the OS.
10. Added Windows Recovery support (Requires customized OS).

---

## [2024-06/07] Initial Release
### 📂 BIOS Files
| Variant  | Compatible Model | Filename | Build Date |
| :--- | :--- | :--- | --- |
| **PCIe** | LattePanda Mu N100 **8GB** | `LP-BS-S70NC1R200-SR-B.bin` | 2024/07/08 |
| **PCIe** | LattePanda Mu N100 / N305 **16GB** | `LP-BS-S70NC1R200-DR-B.bin` | 2024/06/19 |
| **SATA** | LattePanda Mu N100 **8GB** | `LP-BS-S70NC1R200-SR-B-SATA.bin` | 2024/07/05 |
| **SATA** | LattePanda Mu N100 / N305 **16GB** | `LP-BS-S70NC1R200-DR-B-SATA.bin` | 2024/06/20 |

### 📝 Changelog
- Initial BIOS firmware release.

---

# SATA Branch Introduction

Enabled integrated SATA controller on the basis of standard BIOS.

## Interface Configuration

### Special Notes

- **USB2_P6**: Dedicated for USB Type-C, must be used in conjunction with a PD controller, **cannot be used as a standard USB port**.

### HSIO (High-Speed Input/Output)

- **HSIO0**: USB 3.2 10Gbps
- **HSIO1**: USB 3.2 10Gbps
- **HSIO2**: PCIe 3.0 x1
- **HSIO3**: PCIe 3.0 x1
- ==========
- **HSIO8**: PCIe 3.0 x1
- **HSIO9**: PCIe 3.0 x1
- **HSIO10**: SATA 3.0
- **HSIO11**: SATA 3.0
- ==========
- **HSIO6**: PCIe 3.0 x1

### DDI/TCP

- **DDIA**: eDP 1.4b (eDP interface on LattePanda Mu)

- **DDIB**: HDMI 2.0

- **TCP0**: HDMI 2.0

- **TCP1**: USB Type-C (requires external PD controller)

### GPIOs

- **I2C1**: Touch panel (touch connector on LattePanda Mu)
- **I2C2**: Communication with Type-C PD controller
- **GPP_B11**: Type-C PD controller PMCALERT\#
- **GPP_B14**: SATA HDD LED
- **GPP_D0**: WWAN_Power_Off
- **GPP_D1**: WWAN_Reset
- **GPP_D2**: Communication interrupt with Type-C PD controller

Other GPIOs not listed are not allocated specific functions.

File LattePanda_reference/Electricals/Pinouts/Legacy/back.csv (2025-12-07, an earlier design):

Number | Name | Type | Description | Note
2 | FAN1_PWM | O | CPU fan PWM output | SIO GP51
4 | FAN1_TAC | I | CPU fan tachometer input | SIO GP52
6 | TAN2_PWM | O | System fan PWM out | SIO GP36
8 | FAN2_TAC | I | System fan tachometer input | SIO GP37
10 | SIO_UART_TX | O | SuperIO UART transmitter | SIO JP3
12 | SIO_UART_RX | I | SuperIO UART receiver | SIO GP41
14 | GND
16 | HSIO0_RX+ | I | Differential signal input
18 | HSIO0_RX- | I | Differential signal input
20 | GND
22 | HSIO1_RX+ | I | Differential signal input
24 | HSIO1_RX- | I | Differential signal input
26 | GND
28 | HSIO2_RX+ | I | Differential signal input
30 | HSIO2_RX- | I | Differential signal input
32 | GND
34 | HSIO3_RX+ | I | Differential signal input
36 | HSIO3_RX- | I | Differential signal input
38 | GND
40 | HSIO8_RX+ | I | Differential signal input
42 | HSIO8_RX- | I | Differential signal input
44 | GND
46 | HSIO9_RX+ | I | Differential signal input
48 | HSIO9_RX- | I | Differential signal input
50 | GND
52 | HSIO10_RX+ | I | Differential signal input
54 | HSIO10_RX- | I | Differential signal input
56 | GND
58 | HSIO11_RX+ | I | Differential signal input
60 | HSIO11_RX- | I | Differential signal input
62 | GND
64 | HSIO6_RX+ | I | Differential signal input
66 | HSIO6_RX- | I | Differential signal input
68 | GND
70 | USB2_P4 | I/O | USB 2.0 differential signal
72 | USB2_N4 | I/O | USB 2.0 differential signal
74 | GND
76 | USB2_P7 | I/O | USB 2.0 differential signal
78 | USB2_N7 | I/O | USB 2.0 differential signal
80 | GND
82 | USB2_P8 | I/O | USB 2.0 differential signal
84 | USB2_N8 | I/O | USB 2.0 differential signal
86 | GND
88 | REFCLK3+ | O | PCIe reference clock
90 | REFCLK3- | O | PCIe reference clock
92 | GND
94 | REFCLK4+ | O | PCIe reference clock
96 | REFCLK4- | O | PCIe reference clock
98 | GND
100 | PCIECLK_REQ3# | I | REFCLK3 clock request function | SoC GPP_D8
102 | PCIECLK_REQ4# | I | REFCLK4 clock request function | SoC GPP_H19
104 | SMB_ALERT# | I | SMBus alert interrupt | SoC GPP_C2
106 | SMB_CLK | O | SMBus clock | SoC GPP_C0
108 | SMB_DATA | I/O | SMBus data | SoC GPP_C1
110 | GND
112 | USB2_P6 | I/O | USB 2.0 differential signal
114 | USB2_N6 | I/O | USB 2.0 differential signal
116 | GND
118 | GPP_F16 | I/O | GPIO, functions defined by BIOS
120 | GPP_F15 | I/O | GPIO, functions defined by BIOS
122 | GPP_F14 | I/O | GPIO, functions defined by BIOS
124 | GPP_F13 | I/O | GPIO, functions defined by BIOS
126 | GPP_F12 | I/O | GPIO, functions defined by BIOS
128 | GPP_D0 | I/O | GPIO, functions defined by BIOS
130 | GPP_D1 | I/O | GPIO, functions defined by BIOS
132 | GPP_D2 | I/O | GPIO, functions defined by BIOS
134 | GPP_D3 | I/O | GPIO, functions defined by BIOS
136 | GND
138 | SOC_UART2_TXD | O | SoC UART2 transmitter | SoC GPP_F2
140 | SOC_UART2_RXD | I | SoC UART2 receiver | SoC GPP_F1
142 | I2C5_SCL | O | I2C5 clock | SoC GPP_B17
144 | I2C5_SDA | I/O | I2C5 data | SoC GPP_B16
KEY | KEY | KEY | KEY
146 | I2C4_SCL | O | I2C4 clock | SoC GPP_H9
148 | I2C4_SDA | I/O | I2C4 data | SoC GPP_H8
150 | I2C3_SCL | O | I2C3 clock | SoC GPP_B8
152 | I2C3_SDA | I/O | I2C3 data | SoC GPP_B7
154 | I2C2_SCL | O | I2C2 clock | SoC GPP_B6
156 | I2C2_SDA | I/O | I2C2 data | SoC GPP_B5
158 | GND
160 | I2S_MCLK | O | I2S main clock | SoC GPP_D19
162 | I2S_SCLK | O | I2S bit clock | SoC GPP_S0
164 | I2S_SFRM | O | I2S word clock | SoC GPP_S1
166 | I2S_TXD | O | I2S serial data transmitter | SoC GPP_S2
168 | I2S_RXD | I | I2S serial data receiver | SoC GPP_S3
170 | GND
172 | HDA_RST | O | HD Audio reset | SoC GPP_R4
174 | HDA_BCLK | O | HD Audio bit clock | SoC GPP_R0
176 | HDA_SYNC | O | HD Audio sync | SoC GPP_R1
178 | HDA_SDOUT | O | HD Audio serial data out | SoC GPP_R2
180 | HDA_SDIN | I | HD Audio serial data in | SoC GPP_R3
182 | GND
184 | CSI_D_CK+ | I | MIPI CSI-2 Port D Clock
186 | CSI_D_CK- | I | MIPI CSI-2 Port D Clock
188 | GND
190 | CSI_D_D1+ | I | MIPI CSI-2 Port D Data Lane 1
192 | CSI_D_D1- | I | MIPI CSI-2 Port D Data Lane 1
194 | GND
196 | CSI_D_D0+ | I | MIPI CSI-2 Port D Data Lane 0
198 | CSI_D_D0- | I | MIPI CSI-2 Port D Data Lane 0
200 | GND
202 | CSI_C_CK+ | I | MIPI CSI-2 Port C Clock
204 | CSI_C_CK- | I | MIPI CSI-2 Port C Clock
206 | GND
208 | CSI_C_D1+ | I | MIPI CSI-2 Port C Data Lane 1
210 | CSI_C_D1- | I | MIPI CSI-2 Port C Data Lane 1
212 | GND
214 | CSI_C_D0+ | I | MIPI CSI-2 Port C Data Lane 0
216 | CSI_C_D0- | I | MIPI CSI-2 Port C Data Lane 0
218 | GND
220 | TCP1_TXP0 | O | TCP1 DP Lane 0/HDMI TMDS Data2
222 | TCP1_TXN0 | O | TCP1 DP Lane 0/HDMI TMDS Data2
224 | GND
226 | TCP1_TXRXP0 | O | TCP1 DP Lane 1/HDMI TMDS Data1
228 | TCP1_TXRXN0 | O | TCP1 DP Lane 1/HDMI TMDS Data1
230 | GND
232 | TCP1_TXP1 | O | TCP1 DP Lane 2/HDMI TMDS Data0
234 | TCP1_TXN1 | O | TCP1 DP Lane 2/HDMI TMDS Data0
236 | GND
238 | TCP1_TXRXP1 | O | TCP1 DP Lane 3/HDMI TMDS Clock
240 | TCP1_TXRXN1 | O | TCP1 DP Lane 3/HDMI TMDS Clock
242 | GND
244 | TCP1_AUX_P | I/O | TCP1 DP Auxiliary channel
246 | TCP1_AUX_N | I/O | TCP1 DP Auxiliary channel
248 | GND
250 | VDC |  | Main power input 9~20V
252 | VDC |  | Main power input 9~20V
254 | VDC |  | Main power input 9~20V
256 | VDC |  | Main power input 9~20V
258 | VDC |  | Main power input 9~20V
260 | VDC |  | Main power input 9~20V

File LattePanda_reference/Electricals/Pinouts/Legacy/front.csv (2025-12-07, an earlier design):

Number | Name | Type | Description | Note
1 | PWRBTN# | I | Power button, with integrated pull-up | SIO PANSWH#
3 | RSTBTN# | I | Reset button, with integrated pull-up | SoC SYS_RESET#
5 | SLS_S0 | O | Power status, output high when S0(Working) | SIO PSON#
7 | SLS_S3 | O | Power status, output high when S0(Working), S3(Sleep) | SoC GPD5
9 | TSENSE | I | NTC temperature sensor input | SIO TMPIN2
11 | GND
13 | HSIO0_TX+ | O | Differential signal output, coupling capacitor required
15 | HSIO0_TX- | O | Differential signal output, coupling capacitor required
17 | GND
19 | HSIO1_TX+ | O | Differential signal output, coupling capacitor required
21 | HSIO1_TX- | O | Differential signal output, coupling capacitor required
23 | GND
25 | HSIO2_TX+ | O | Differential signal output, coupling capacitor required
27 | HSIO2_TX- | O | Differential signal output, coupling capacitor required
29 | GND
31 | HSIO3_TX+ | O | Differential signal output, coupling capacitor required
33 | HSIO3_TX- | O | Differential signal output, coupling capacitor required
35 | GND
37 | HSIO8_TX+ | O | Differential signal output, coupling capacitor required
39 | HSIO8_TX- | O | Differential signal output, coupling capacitor required
41 | GND
43 | HSIO9_TX+ | O | Differential signal output, coupling capacitor required
45 | HSIO9_TX- | O | Differential signal output, coupling capacitor required
47 | GND
49 | HSIO10_TX+ | O | Differential signal output, coupling capacitor required
51 | HSIO10_TX- | O | Differential signal output, coupling capacitor required
53 | GND
55 | HSIO11_TX+ | O | Differential signal output, coupling capacitor required
57 | HSIO11_TX- | O | Differential signal output, coupling capacitor required
59 | GND
61 | HSIO6_TX+ | O | Differential signal output, coupling capacitor required
63 | HSIO6_TX- | O | Differential signal output, coupling capacitor required
65 | GND
67 | USB2_P1- | I/O | USB 2.0 differential signal
69 | USB2_P1+ | I/O | USB 2.0 differential signal
71 | GND
73 | USB2_P2- | I/O | USB 2.0 differential signal
75 | USB2_P2+ | I/O | USB 2.0 differential signal
77 | GND
79 | USB2_P3- | I/O | USB 2.0 differential signal
81 | USB2_P3+ | I/O | USB 2.0 differential signal
83 | GND
85 | REFCLK0+ | O | PCIe reference clock
87 | REFCLK0- | O | PCIe reference clock
89 | GND
91 | REFCLK1+ | O | PCIe reference clock
93 | REFCLK1- | O | PCIe reference clock
95 | GND
97 | REFCLK2+ | O | PCIe reference clock
99 | REFCLK2- | O | PCIe reference clock
101 | GND
103 | WAKE# | I | Wake Mu when pull-down | SoC WAKE#
105 | PLTRST# | O | Platform reset signal | SoC GPP_B13
107 | GND
109 | USB2_P5- | I/O | USB 2.0 differential signal
111 | USB2_P5+ | I/O | USB 2.0 differential signal
113 | GND
115 | VBAT |  | RTC battery input | SoC VCCRTC
117 | PROCHOT# | I | Overheat protect when pull-down | SoC PROCHOT#
119 | GPP_E0 | I/O | GPIO, functions defined by BIOS
121 | GPP_A12 | I/O | GPIO, functions defined by BIOS
123 | GPP_B14 | I/O | GPIO, functions defined by BIOS
125 | GPP_B11 | I/O | GPIO, functions defined by BIOS
127 | TPM_IRQ | I | discrete TPM interrupt | SoC GPP_B4
129 | USB_OC# | I | USB over current signal | SoC GPP_A16
131 | SUSCLK | O | 32.768kHz clock output | SoC GPD8
133 | BIOS_SEL# | I | BIOS select: pull-up: integrated ROM; pull-down: carrier ROM
135 | GND
137 | UART0_RXD | I | SoC UART0 receiver | SoC GPP_H10
139 | UART0_TXD | O | SoC UART0 transmitter | SoC GPP_H11
141 | UART1_RXD | I | SoC UART1 receiver | SoC GPP_D17
143 | UART1_TXD | O | SoC UART1 transmitter | SoC GPP_D18
KEY | KEY | KEY | KEY
145 | SML1_DATA | I/O | SMLink1 data | SoC GPP_C7
147 | SML1_CLK | O | SMLink1 clock | SoC GPP_C6
149 | SML1_ALERT# | I | SMLink1 alert | SoC GPP_B23
151 | GND
153 | SPI_IO3 | I/O | SPI interface, BIOS and dTPM specific
155 | SPI_CLK | O | SPI interface, BIOS and dTPM specific
157 | SPI_CS2# | O | SPI chip select, dTPM specific
159 | SPI_MOSI/SPI_IO0 | I/O | SPI interface, BIOS and dTPM specific
161 | SPI_IO2 | I/O | SPI interface, BIOS and dTPM specific
163 | SPI_MISO/SPI_IO1 | I/O | SPI interface, BIOS and dTPM specific
165 | SPI_CS# | O | SPI chip select, BIOS ROM specific
167 | GND
169 | DDIB_DDC_SDA | I/O | DDIB HDMI display data channel data | SoC GPP_H17
171 | DDIB_DDC_SCL | O | DDIB HDMI display data channel clock | SoC GPP_H15
173 | TCP1_DDC_SDA | I/O | TCP1 HDMI display data channel data | SoC GPP_E21
175 | TCP1_DDC_SCL | O | TCP1 HDMI display data channel clock | SoC GPP_E20
177 | TCP0_DDC_SDA | I/O | TCP0 HDMI display data channel data | SoC GPP_E19
179 | TCP0_DDC_SCL | O | TCP0 HDMI display data channel clock | SoC GPP_E18
181 | GND
183 | DDIB_HPD | I | DDIB hot plug detect | SoC GPP_A18
185 | TCP1_HPD | I | TCP1 hot plug detect | SoC GPP_A20
187 | TCP0_HPD | I | TCP0 hot plug detect | SoC GPP_A19
189 | GND
191 | DDIB_AUX- | I/O | DDIB DP Auxiliary channel
193 | DDIB_AUX+ | I/O | DDIB DP Auxiliary channel
195 | GND
197 | DDIB_TX3- | O | DDIB DP Lane 3/HDMI TMDS Clock
199 | DDIB_TX3+ | O | DDIB DP Lane 3/HDMI TMDS Clock
201 | GND
203 | DDIB_TX2- | O | DDIB DP Lane 2/HDMI TMDS Data0
205 | DDIB_TX2+ | O | DDIB DP Lane 2/HDMI TMDS Data0
207 | GND
209 | DDIB_TX1- | O | DDIB DP Lane 1/HDMI TMDS Data1
211 | DDIB_TX1+ | O | DDIB DP Lane 1/HDMI TMDS Data1
213 | GND
215 | DDIB_TX0- | O | DDIB DP Lane 0/HDMI TMDS Data2
217 | DDIB_TX0+ | O | DDIB DP Lane 0/HDMI TMDS Data2
219 | GND
221 | TCP0_AUX- | I/O | TCP0 DP Auxiliary channel
223 | TCP0_AUX+ | I/O | TCP0 DP Auxiliary channel
225 | GND
227 | TCP0_TXRX1- | O | TCP0 DP Lane 3/HDMI TMDS Clock
229 | TCP0_TXRX1+ | O | TCP0 DP Lane 3/HDMI TMDS Clock
231 | GND
233 | TCP0_TX1- | O | TCP0 DP Lane 2/HDMI TMDS Data0
235 | TCP0_TX1+ | O | TCP0 DP Lane 2/HDMI TMDS Data0
237 | GND
239 | TCP0_TXRX0- | O | TCP0 DP Lane 1/HDMI TMDS Data1
241 | TCP0_TXRX0+ | O | TCP0 DP Lane 1/HDMI TMDS Data1
243 | GND
245 | TCP0_TX0- | O | TCP0 DP Lane 0/HDMI TMDS Data2
247 | TCP0_TX0+ | O | TCP0 DP Lane 0/HDMI TMDS Data2
249 | GND
251 | VIN |  | Main power input 9~20V
253 | VIN |  | Main power input 9~20V
255 | VIN |  | Main power input 9~20V
257 | VIN |  | Main power input 9~20V
259 | VIN |  | Main power input 9~20V

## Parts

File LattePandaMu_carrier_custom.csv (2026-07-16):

Reference | Qty | Value | DNP | Exclude from BOM | Exclude from Board | Footprint | Datasheet
A1 | 1 | LattePanda_Mu |  |  |  | Module_LattePanda:LattePanda_Module_H8.0mm_Horizontal
BT1 | 1 | Battery_Cell |  |  |  | A_HDJ_Library:Battery_Holder_CR1220_S8411-45R | ~
C1,C2,C3,C4,C5,C6,C7,C8 | 8 | 220nF/50V | DNP |  | Excluded from board | A_HDJ_Library:C_0402_1005Metric | ~
C9,C10,C13,C15,C85 | 5 | 100nF/50V | DNP |  | Excluded from board | A_HDJ_Library:C_0402_1005Metric | ~
C11 | 1 | 100uF/25V | DNP |  | Excluded from board | A_HDJ_Library:CP_Elec_6.3x7.7 | ~
C14 | 1 | 10uF/10V | DNP |  | Excluded from board | A_HDJ_Library:C_0402_1005Metric | ~
C16 | 1 | 560uF/25V | DNP |  | Excluded from board | A_HDJ_Library:CP_Elec_6.3x7.7 | ~
C17,C18,C19,C20,C21,C22,C23,C24,C25,C26,C27,C28,C29,C33,C34,C35,C36,C37,C38,C39,C40,C41,C42,C43,C45,C48,C52,C54,C58,C60,C84 | 31 | 100nF/50V |  |  |  | A_HDJ_Library:C_0402_1005Metric | ~
C30,C31,C32,C64,C65,C67,C68,C74,C75,C76,C77,C80,C81,C82,C83 | 15 | 22uF/10V |  |  |  | A_HDJ_Library:C_0603_1608Metric | ~
C44,C51,C53,C57,C59 | 5 | 10uF/50V |  |  |  | A_HDJ_Library:C_0402_1005Metric | ~
C46,C47 | 2 | 12pF/50V |  |  |  | A_HDJ_Library:C_0402_1005Metric | ~
C49,C50,C55,C56 | 4 | 220nF/50V |  |  |  | A_HDJ_Library:C_0402_1005Metric | ~
C61,C66,C69 | 3 | 1uF/16V |  |  |  | A_HDJ_Library:C_0402_1005Metric | ~
C62,C63 | 2 | 1uF/16V | DNP |  | Excluded from board | A_HDJ_Library:C_0402_1005Metric | ~
C70,C71 | 2 | 100nF/50V |  |  |  | A_HDJ_Library:C_0603_1608Metric | ~
C72 | 1 | 12pF/50V | DNP |  | Excluded from board | A_HDJ_Library:C_0402_1005Metric | ~
C73 | 1 | 12pF/50V | DNP |  |  | A_HDJ_Library:C_0402_1005Metric | ~
C78,C79 | 2 | 100nF/10V |  |  |  | A_HDJ_Library:C_0603_1608Metric | ~
D1,D2,D3 | 3 | ESD5V0B03 |  |  |  | A_HDJ_Library:D_0402_1005Metric | https://www.onsemi.com/pub/Collateral/ESD9B-D.PDF
D4,D26 | 2 | 1N5819WS |  |  |  | A_HDJ_Library:D_SOD-323 | https://datasheet.lcsc.com/lcsc/2204281430_Guangdong-Hottech-1N5819WS_C191023.pdf
D5,D6,D7,D8,D10,D11,D21,D25 | 8 | ESD9B5.0ST5G |  |  |  | A_HDJ_Library:D_0402_1005Metric | https://www.onsemi.com/pub/Collateral/ESD9B-D.PDF
D9 | 1 | LED_G |  |  |  | A_HDJ_Library:LED_0603_1608Metric | ~
D12,D13,D14 | 3 | D_Zener |  |  |  | A_HDJ_Library:D_0402_1005Metric | ~
D15,D16,D17,D18,D19,D20 | 6 | D_Schottky |  |  |  | A_HDJ_Library:D_SMA | ~
D22 | 1 | LED |  |  |  | A_HDJ_Library:LED_0603_1608Metric | ~
D23 | 1 | LED | DNP |  | Excluded from board | A_HDJ_Library:LED_0603_1608Metric | ~
D24 | 1 | 3V3 Izt=5mA |  |  |  | A_HDJ_Library:D_SOD-323 | ~
D27 | 1 | 1N5819WS | DNP |  | Excluded from board | A_HDJ_Library:D_SOD-323 | https://datasheet.lcsc.com/lcsc/2204281430_Guangdong-Hottech-1N5819WS_C191023.pdf
F1 | 1 | 6V/50mA |  |  |  | A_HDJ_Library:C_0603_1608Metric | ~
F2,F3,F4,F5 | 4 | 6V/1A |  |  |  | A_HDJ_Library:Fuse_0805_2012Metric | ~
FID1,FID2 | 2 | Fiducial |  | Excluded from BOM |  | A_HDJ_Library:Fiducial_0.5mm_Mask1mm | ~
H1,H2,H3,H4,H7,H8 | 6 | MountingHole_Pad |  | Excluded from BOM |  | A_HDJ_Library:MountingHole_3.2mm_M3_Pad_Via | ~
H5,H6 | 2 | MountingHole_Pad |  | Excluded from BOM |  | A_HDJ_Library:MountingHole_3mm_M2_Pad_TopOnly | ~
J1,J8,J10,J11,J14 | 5 | Conn_01x03_Pin |  |  |  | A_HDJ_Library:PinHeader_1x03_P2.54mm_Vertical | ~
J2 | 1 | Bus_PCI_Express_x4 | DNP |  | Excluded from board | A_HDJ_Library:PCIe_x4_Gen3Slot_Connectors | http://www.ritrontek.com/uploadfile/2016/1026/20161026105231124.pdf#page=63
J3 | 1 | HDMI_A |  |  |  | A_HDJ_Library:HDMI_A_Molex_208658-1001_Horizontal | https://en.wikipedia.org/wiki/HDMI
J4 | 1 | USB3_A_Stacked |  |  |  | A_HDJ_Library:USB3_A_Molex_48406-0001_Horizontal_Stacked | ~
J5 | 1 | USB_A_Stacked |  |  |  | A_HDJ_Library:USB_A_CUI_UJ2-ADH-TH_Horizontal_Stacked | ~
J6 | 1 | RJ45_RB1-125B8G1A |  |  |  | A_HDJ_Library:RJ45_UDE_RB1-125B8G1A | https://datasheet.lcsc.com/szlcsc/1901091107_UDE-Corp-RB1-125B8G1A_C363353.pdf
J7,J9,J12,J13,J19,J20,J21 | 7 | Conn_01x04_Pin |  |  |  | A_HDJ_Library:PinHeader_1x04_P2.54mm_Vertical | ~
J15 | 1 | Bus_M.2_Socket_M |  |  |  | A_HDJ_Library:PCIe_M.2_Connectors_P=0.5mm_H=4.2mm_KeyM | https://web.archive.org/web/20200613074028/http://read.pudn.com/downloads794/doc/project/3133918/PCIe_M.2_Electromechanical_Spec_Rev1.0_Final_11012013_RS_Clea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
J16 | 1 | Bus_M.2_Socket_E |  |  |  | A_HDJ_Library:PCIe_M.2_Connectors_P=0.5mm_H=4.2mm_KeyE | https://web.archive.org/web/20200613074028/http://read.pudn.com/downloads794/doc/project/3133918/PCIe_M.2_Electromechanical_Spec_Rev1.0_Final_11012013_RS_Clea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
J17 | 1 | Barrel_Jack_Switch |  |  |  | A_HDJ_Library:DC_Jack_DC007B_30V_10A | ~
J18 | 1 | USB_C_Receptacle_USB2.0_16P |  |  |  | A_HDJ_Library:USB_C_Receptacle_G-Switch_GT-USB-7010ASV | https://www.usb.org/sites/default/files/documents/usb_type-c.zip
JP1 | 1 | Jumper_3_Bridged12 |  | Excluded from BOM |  | A_HDJ_Library:PinHeader_1x03_P2.54mm_Vertical | ~
JP2 | 1 | NTC_Test | DNP | Excluded from BOM | Excluded from board | Jumper:SolderJumper-2_P1.3mm_Open_RoundedPad1.0x1.5mm | ~
L1,L2 | 2 | 2.2uH/4.3A |  |  |  | A_HDJ_Library:L_Sunlord_SWPA4020S | ~
M1 | 1 | Fan_4pin |  |  |  | A_HDJ_Library:JST_PH_B4B-PH-K_1x04_P2.00mm_Vertical | http://www.formfactors.org/developer%5Cspecs%5Crev1_2_public.pdf
M2 | 1 | Fan_4pin | DNP |  | Excluded from board | A_HDJ_Library:JST_PH_B4B-PH-K_1x04_P2.00mm_Vertical | http://www.formfactors.org/developer%5Cspecs%5Crev1_2_public.pdf
Q1,Q8 | 2 | 2N7002 |  |  |  | A_HDJ_Library:SOT-23 | https://www.onsemi.com/pub/Collateral/NDS7002A-D.PDF
Q2,Q3,Q4 | 3 | 2SK3018 |  |  |  | A_HDJ_Library:SOT-23 | https://www.onsemi.com/pub/Collateral/NDS7002A-D.PDF
Q5,Q6 | 2 | 2N7002 | DNP |  | Excluded from board | A_HDJ_Library:SOT-23 | https://www.onsemi.com/pub/Collateral/NDS7002A-D.PDF
Q7 | 1 | AON7262E | DNP |  | Excluded from board | A_HDJ_Library:MOSFET_PDFN8_3.3x3.3 | https://datasheet.lcsc.com/szlcsc/Alpha-Omega-Semicon-AOS-AON7262E_C176755.pdf
R1,R11,R37,R47 | 4 | 1K/1% |  |  |  | A_HDJ_Library:R_0402_1005Metric | ~
R2,R20,R21,R34,R35,R36,R49,R58,R78,R79 | 10 | 10K/1% |  |  |  | A_HDJ_Library:R_0402_1005Metric | ~
R3,R5,R15,R18,R19,R52,R53 | 7 | 2.2K/1% |  |  |  | A_HDJ_Library:R_0402_1005Metric | ~
R4,R23 | 2 | 1M/1% |  |  |  | A_HDJ_Library:R_0402_1005Metric | ~
R6,R59,R68 | 3 | 21.5K/1% |  |  |  | A_HDJ_Library:R_0402_1005Metric | ~
R7,R8,R9,R10,R13,R14,R16,R17,R24,R25 | 10 | 470R/1% |  |  |  | A_HDJ_Library:R_0402_1005Metric | ~
R22 | 1 | 2.49K/1% |  |  |  | A_HDJ_Library:R_0603_1608Metric | ~
R27,R29,R32,R33 | 4 | 0R/1% |  |  |  | A_HDJ_Library:R_0402_1005Metric | ~
R28,R73,R75 | 3 | 0R/1% | DNP |  | Excluded from board | A_HDJ_Library:R_0402_1005Metric | ~
R38,R40,R50,R56,R63 | 5 | 10K/1% | DNP |  | Excluded from board | A_HDJ_Library:R_0402_1005Metric | ~
R39 | 1 | 2.2K/1% | DNP |  | Excluded from board | A_HDJ_Library:R_0402_1005Metric | ~
R41,R42,R54,R66,R67,R70 | 6 | 21.5K/1% | DNP |  | Excluded from board | A_HDJ_Library:R_0402_1005Metric | ~
R43 | 1 | 56K/1% |  |  |  | A_HDJ_Library:R_0402_1005Metric | ~
R44,R45 | 2 | 100K/1% | DNP |  | Excluded from board | A_HDJ_Library:R_0402_1005Metric | ~
R46,R51,R76,R77 | 4 | 100K/1% |  |  |  | A_HDJ_Library:R_0402_1005Metric | ~
R48,R55,R69 | 3 | 100R/1% |  |  |  | A_HDJ_Library:R_0402_1005Metric | ~
R57 | 1 | 75K/1% |  |  |  | A_HDJ_Library:R_0402_1005Metric | ~
R60,R72 | 2 | 4.7K/1% |  |  |  | A_HDJ_Library:R_0402_1005Metric | ~
R64,R65,R74 | 3 | 4.7K/1% | DNP |  | Excluded from board | A_HDJ_Library:R_0402_1005Metric | ~
R71 | 1 | 100R/1% | DNP |  | Excluded from board | A_HDJ_Library:R_0402_1005Metric | ~
SW1,SW2 | 2 | SW_Push |  |  |  | A_HDJ_Library:SW_Push_6x6x6 | ~
TH1 | 1 | NTC-10K | DNP |  | Excluded from board | A_HDJ_Library:R_0603_1608Metric | ~
TP1,TP8,TP9 | 3 | TestPoint | DNP |  | Excluded from board | A_HDJ_Library:TestPoint_Pad_D1.5mm | ~
TP2,TP3,TP4,TP5,TP6,TP7,TP10,TP11,TP12,TP13 | 10 | TestPoint |  |  |  | A_HDJ_Library:TestPoint_Pad_D1.5mm | ~
U1,U2,U3,U4,U5 | 5 | D3V3XA4B10LP |  |  |  | A_HDJ_Library:Diodes_UDFN-10_1.0x2.5mm_P0.5mm | https://www.diodes.com/assets/Datasheets/D3V3XA4B10LP.pdf
U6 | 1 | RTL8111H-CG-RH |  |  |  | A_HDJ_Library:QFN-32-1EP_4x4mm_P0.4mm_EP2.65x2.65mm
U7,U8 | 2 | D3V3XA4B10LP | DNP |  |  | A_HDJ_Library:Diodes_UDFN-10_1.0x2.5mm_P0.5mm | https://www.diodes.com/assets/Datasheets/D3V3XA4B10LP.pdf
U9,U10,U11,U12,U17 | 5 | ULC0524P |  |  |  | A_HDJ_Library:Diodes_UDFN-10_1.0x2.5mm_P0.5mm | https://www.diodes.com/assets/Datasheets/D3V3XA4B10LP.pdf
U13 | 1 | TL431DBZ | DNP |  | Excluded from board | A_HDJ_Library:SOT-23 | http://www.ti.com/lit/ds/symlink/tl431.pdf
U14 | 1 | USB PD等快充协议受电芯片-CH224K-ESSOP10 |  |  |  | A_HDJ_Library:ESSOP-10-1EP_3.9x5mm_P1.0mm_EP3.2x2.3
U15,U16 | 2 | LM2734X |  |  |  | A_HDJ_Library:TSOT-23-6 | http://www.ti.com/lit/ds/symlink/lm2734.pdf
Y1 | 1 | 25MHz |  |  |  | A_HDJ_Library:Crystal_SMD_3225-4Pin_3.2x2.5mm | ~

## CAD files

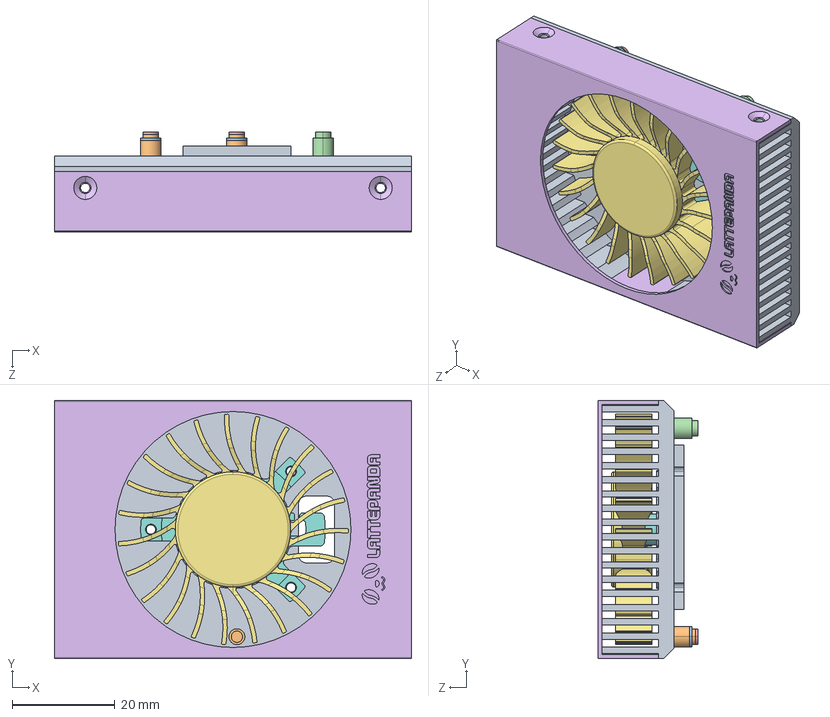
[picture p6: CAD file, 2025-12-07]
LattePanda_reference/Mechanicals/FIT0981_Active_cooler.STEP
69.6 x 50.4 x 19.5 mm
BREP_2.STEP
BREP_960.STEP
BREP_961.STEP
BREP_962.STEP
0105______6pcs.STEP
YE.STEP
ZUO.STEP

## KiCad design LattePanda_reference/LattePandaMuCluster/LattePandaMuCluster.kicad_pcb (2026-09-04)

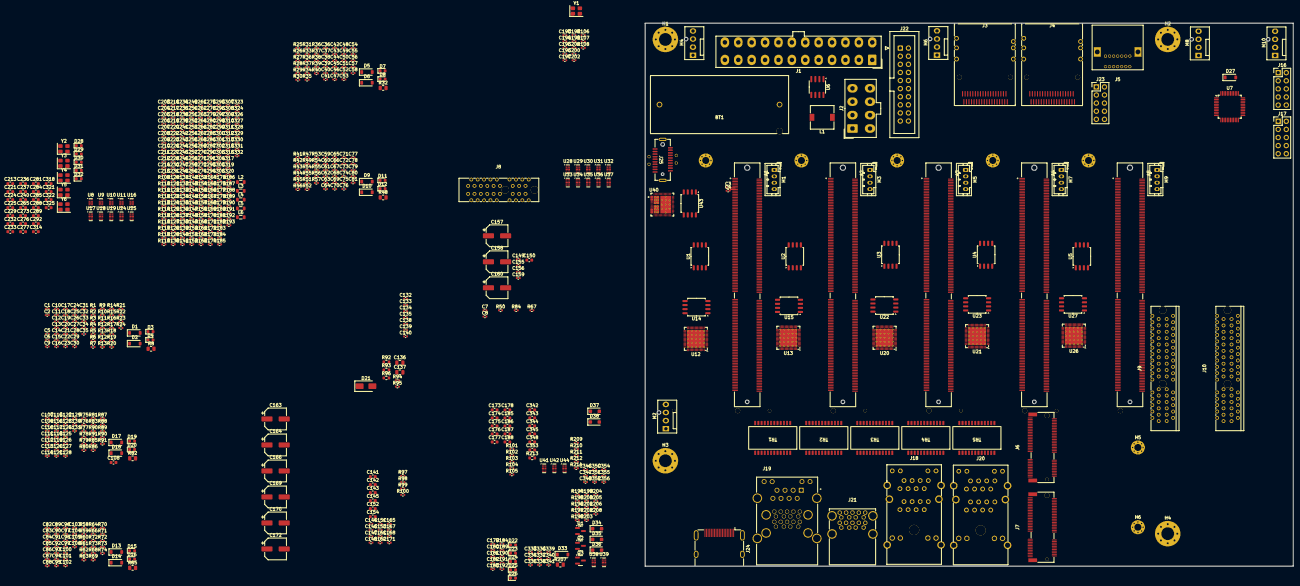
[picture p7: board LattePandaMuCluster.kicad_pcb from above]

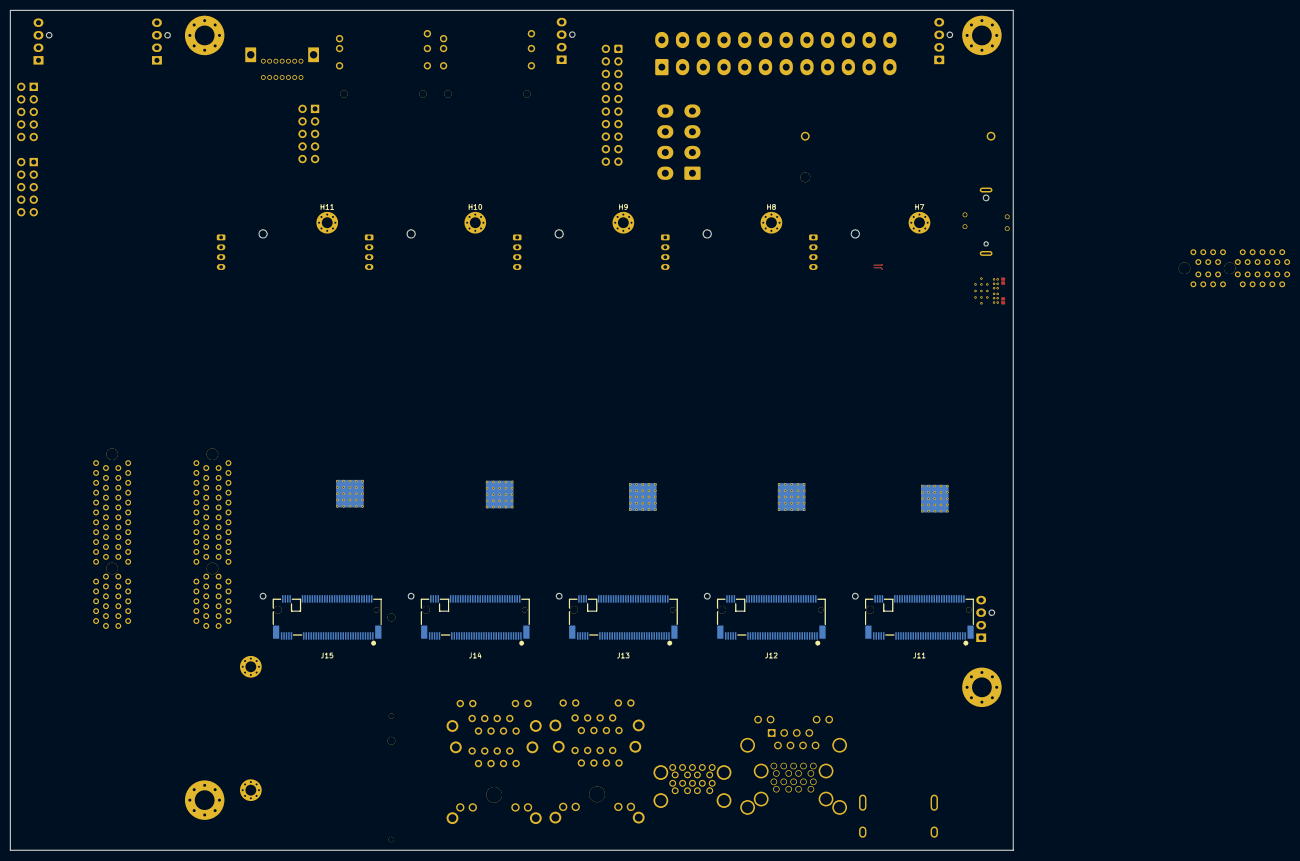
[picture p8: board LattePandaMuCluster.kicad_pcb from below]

Board: 4 copper layers, 203.2 x 170.2 mm, 734 parts (10 on the bottom side), 818 nets.

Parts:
A1, A2, A3, A4, A5: LattePanda_Mu; ATTEND_124B-150A02
BT1: Battery_Cell; BAT-TH_BH-123A-A5BJ002
C1, C2, C3, C4, C5, C6, C23, C26, C27, C36, C37, C38, C39, C40, C41, C58, C59, C60, C61, C62, C63, C64, C81, C82, C83, C106, C107, C131, C132, C144, C146, C147, C148, C179, C180, C181, C182, C183, C184, C189, C190, C191, C192, C194, C195, C197, C203, C204, C205, C206, C207, C208, C209, C210, C211, C212, C214, C215, C216, C217, C218, C219, C220, C222, C223, C226, C227, C228, C230, C231, C234, C235, C238, C239, C245, C247, C255, C256, C257, C258, C259, C260, C261, C262, C263, C264, C266, C267, C268, C269, C270, C271, C272, C274, C275, C278, C279, C280, C282, C283, C286, C287, C290, C291, C297, C299, C307, C308, C309, C310, C311, C312, C313, C315, C316, C317, C319, C320, C323, C324, C328, C333, C334, C335, C336, C337, C338, C339, C340, C341, C356: 100nF; C_0402_1005Metric
C7, C8, C9, C10, C11, C12, C21, C22, C30, C31, C34, C35, C42, C43, C44, C45, C46, C47, C56, C57, C65, C66, C67, C68, C69, C70, C79, C80, C84, C85, C86, C87, C88, C89, C90, C91, C92, C93, C94, C95, C104, C105, C109, C110, C111, C112, C113, C114, C115, C116, C117, C118, C119, C120, C129, C130, C241, C242, C243, C244, C293, C294, C295, C296, C326, C327: 220nF; C_0402_1005Metric
C13, C14, C15, C16, C17, C18, C19, C20, C48, C49, C50, C51, C52, C53, C54, C55, C71, C72, C73, C74, C75, C76, C77, C78, C96, C97, C98, C99, C100, C101, C102, C103, C121, C122, C123, C124, C125, C126, C127, C128, C133, C138, C198, C349, C350, C351, C352: 10nF; C_0402_1005Metric
C24, C25, C249, C250, C301, C302, C330: 100pF; C_0402_1005Metric
C28, C29, C32, C33: 330nF; C_0402_1005Metric
C108: 100nF; C_0603_1608Metric
C134, C135, C193: 4.7uF; C_0402_1005Metric
C136, C137: 47uF; C_0805_2012Metric
C139: 1nF; C_0402_1005Metric
C140: 47pF; C_0402_1005Metric
C141, C142, C143, C145, C173, C174, C175, C176, C177, C178, C185, C186, C187, C188, C342, C343, C344, C345, C348: 10uF; C_0603_1608Metric
C149, C151, C153, C155, C156, C159, C161, C162, C165, C167, C168, C171: 100nF/50V; C_0402_1005Metric
C150, C152, C154: 10uF/10V; C_0603_1608Metric
C157, C158, C163, C164, C169, C170: 100uF/25V; CP_Elec_6.3x7.7
C160, C166, C172: 560uF/25V; CP_Elec_6.3x7.7
C196, C199, C200, C346, C347: 1uF; C_0402_1005Metric
C201, C202, C251, C252, C253, C254, C303, C304, C305, C306, C331, C332: 27pF; C_0402_1005Metric
C213, C221, C224, C225, C229, C232, C233, C236, C237, C240, C265, C273, C276, C277, C281, C284, C285, C288, C289, C292, C314, C318, C321, C322, C325, C353: 22uF; C_0603_1608Metric
C246, C248, C298, C300, C329: 390pF; C_0402_1005Metric
C354, C355: 220pF; C_0402_1005Metric
D1, D2, D5, D6, D9, D10, D13, D14, D17, D18, D27, D33: B0520W; D_SOD-123
D3, D4, D7, D8, D11, D12, D15, D16, D19, D20, D22, D23, D24, D25, D26, D28, D29, D30, D31, D32: LED; LED_0603_1608Metric
D21: SSL345F; D_SMA
D34, D35, D36, D37, D38: SMF33A; D_SOD-123F
H1, H2, H3, H4: MountingHole_Pad; MountingHole_4mm_Pad_Via
H5, H6, H7, H8, H9, H10, H11: MountingHole_Pad; MountingHole_2.2mm_M2_Pad_Via
J1: ATX-24; Molex_Mini-Fit_Jr_5566-24A_2x12_P4.20mm_Vertical
J2: Conn_02x04_Top_Bottom; Molex_Mini-Fit_Jr_5566-08A_2x04_P4.20mm_Vertical
J3, J4: SFF-8087; CONN-SMD_LD2136V-MCUL6
J5: SATA; CONN-TH_XUTS-0722-2070
J6, J7: Bus_M.2_Socket_E; CONN-SMD_AS0BC21-S48BE-7H
J8: Bus_PCI_Express_x1; CONN-TH_HYCW05-PCI36-155B
J9, J10: Bus_PCI_Express_x4; PCIE-TH_AAA-PCI-161-K03
J11, J12, J13, J14, J15: Bus_M.2_Socket_M; CONN-SMD_AS0BC21-S30BM-7H
J16, J17, J23: Conn_02x05_Odd_Even; PinHeader_2x05_P2.54mm_Vertical
J18, J20: RJ45_LED_Shielded_x2; RJ45-TH_HC-RJ45-059C
J19: RJE361882415; AMPHENOL_RJE361882415
J21: USB3_A_Stacked; USB-A-TH_HC-USB3.0-L175-2X1-J
J22: USB3_IDC; IDC-Header_2x10_P2.54mm_Vertical
J24: HDMI_A; HDMI_A_Molex_208658-1001_Horizontal
J25: JACK-USBE-20PINTL
L1: 6.8uH; L_7.3x7.3_H3.5
L2, L3, L4, L5, L6: 1uH; L_0805_2012Metric
M1, M3, M5, M7, M9: Fan_4pin; JST_PH_B4B-PH-K_1x04_P2.00mm_Vertical
M2, M4, M6, M8, M10: Fan_4pin; FanPinHeader_1x04_P2.54mm_Vertical
Q1, Q2, Q3: 2N7002; SOT-23
R1, R2, R25, R26, R41, R42, R58, R59, R75, R76: 4.7k; R_0402_1005Metric
R3, R4, R7, R27, R28, R31, R43, R44, R47, R60, R61, R64, R77, R78, R81, R115, R117, R149, R151, R180, R208: 22k; R_0402_1005Metric
R5, R6, R10, R11, R13#2, R14, R15, R16, R17, R18, R29, R30, R45, R46, R62, R63, R79, R80: 100R; R_0402_1005Metric
R8, R32, R48, R65, R82, R207: 1k; R_0805_2012Metric
R9, R12, R33, R34, R49, R51, R66, R68, R83, R85, R101, R102, R103, R104, R105, R202, R203, R205, R206: 2.2k; R_0402_1005Metric
R12#2, R13, R19, R20, R22, R36, R36#2, R37, R37#2, R39, R50, R53, R54, R54#2, R55, R56, R67, R70, R71, R72, R73, R73#2, R84, R87, R88, R90, R90#2, R91, R97, R98, R99, R100, R108, R109, R110, R111, R112, R131, R132, R133, R134, R135, R136, R137, R138, R139, R140, R141, R142, R143, R144, R145, R146, R165, R166, R167, R168, R169, R170, R171, R172, R173, R174, R175, R176, R177, R178, R188, R189, R190, R191, R192, R193, R209, R210, R212, R214: 10k; R_0402_1005Metric
R21, R23, R24, R35, R38, R40, R52, R55#2, R57, R69, R72#2, R74, R86, R89, R91#2, R211: 100k; R_0402_1005Metric
R92: 82k; R_0603_1608Metric
R93: 27k; R_0603_1608Metric
R94: 75k; R_0402_1005Metric
R95: 24k; R_0402_1005Metric
R96: 30k; R_0603_1608Metric
R106, R107, R113, R114, R116, R118, R129, R130, R147, R148, R150, R152, R163, R164, R179, R181, R187: 510R; R_0402_1005Metric
R119, R120, R153, R154, R182: 200R; R_0402_1005Metric
R121, R122, R123, R124, R125, R126, R127, R128, R155, R156, R157, R158, R159, R160, R161, R162, R183, R184, R185, R186: 75R; R_0402_1005Metric
R194, R195, R196, R197, R198, R199, R200, R201: 470R; R_0402_1005Metric
R204: 1M; R_0402_1005Metric
R213: 62k; R_0603_1608Metric
TR1, TR2, TR3, TR4, TR5: QG2439S
U1, U2, U3, U4, U5, U14, U15, U22, U23, U27, U43: ZD25Q64BSIGT; SOIC-8_5.3x5.3mm_P1.27mm
U6: TPS54331; SOIC-8_3.9x4.9mm_P1.27mm
U7: STM32F030C8Tx; LQFP-48_7x7mm_P0.5mm
U8, U9, U10, U11, U16, U17, U18, U19, U24, U25, U28, U29, U30, U31, U32, U33, U34, U35, U36, U37, U38, U39, U41, U42, U44: H5VU25U; Diodes_UDFN-10_1.0x2.5mm_P0.5mm
U12, U13, U20, U21, U26: KTI226V; QFN-56-1EP_7x7mm_P0.4mm_EP5.6x5.6mm_ThermalVias
U40: TPS65987DDJRSHR; RSH0056E-MFG
Y1, Y2, Y3, Y4, Y5, Y6: 25MHz; Crystal_SMD_3225-4Pin_3.2x2.5mm

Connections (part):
+3V3: C23.1, C58.1, C81.1, C106.1, C131.1, C141.1, C142.1, C143.1, C144.1, C145.1, C146.1, C147.1, C148.1, C159.1, C160.1, C165.1, C166.1, C171.1, C172.1, C173.1, C174.1, C175.1, C176.1, C177.1, C178.1, C179.1, C180.1, C181.1, C182.1, C183.1, C184.1, C185.1, C186.1, C187.1, C188.1, C189.1, C190.1, C191.1, C192.1, J1.1 (+3.3V), J1.2 (+3.3V), J1.12 (+3.3V), J1.13 (+3.3V), J6.2 (3.3V), J6.4 (3.3V), J6.72 (3.3V), J6.74 (3.3V), J7.2 (3.3V), J7.4 (3.3V), J7.72 (3.3V), J7.74 (3.3V), J8.A9 (+3.3V), J8.A10 (+3.3V), J8.B8 (+3.3V), J9.A9 (+3.3V), J9.A10 (+3.3V), J9.B8 (+3.3V), J10.A9 (+3.3V), J10.A10 (+3.3V), J10.B8 (+3.3V), J11.2 (3.3V), J11.4 (3.3V), J11.12 (3.3V), J11.14 (3.3V), J11.16 (3.3V), J11.18 (3.3V), J11.70 (3.3V), J11.72 (3.3V), J11.74 (3.3V), J12.2 (3.3V), J12.4 (3.3V), J12.12 (3.3V), J12.14 (3.3V), J12.16 (3.3V), J12.18 (3.3V), J12.70 (3.3V), J12.72 (3.3V), J12.74 (3.3V), J13.2 (3.3V), J13.4 (3.3V)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
+3V3SB: C136.1, C137.1, C149.2, C150.2, C151.2, C152.2, C153.2, C154.2, C203.2, C204.2, C205.1, C206.2, C207.2, C208.1, C211.2, C212.1, C213.2, C214.1, C217.2, C218.1, C221.2, C222.1, C225.2, C226.1, C229.2, C230.1, C233.2, C234.1, C237.2, C238.1, C245.1, C247.1, C255.2, C256.2, C257.1, C258.2, C259.2, C260.1, C263.2, C264.1, C265.2, C266.1, C269.2, C270.1, C273.2, C274.1, C277.2, C278.1, C281.2, C282.1, C285.2, C286.1, C289.2, C290.1, C297.1, C299.1, C307.2, C308.2, C309.1, C310.2, C311.1, C314.2, C315.1, C318.2, C319.1, C322.2, C323.1, C328.1, C348.2, C356.1, D27.2 (A), J8.B10 (3.3Vaux), J9.B10 (3.3Vaux), J10.B10 (3.3Vaux), L1.2, R94.2, R109.1, R110.1, R111.1, R112.1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
+5V: C1.1, C36.1, C59.1, C82.1, C107.1, D1.1 (K), D5.1 (K), D9.1 (K), D13.1 (K), D17.1 (K), D33.2 (A), J1.4 (+5V), J1.6 (+5V), J1.21 (+5V), J1.22 (+5V), J1.23 (+5V), M1.2 (+), M3.2 (+), M5.2 (+), M7.2 (+), M9.2 (+), R1.1, R25.1, R41.1, R58.1, R75.1
+5VHDMI: C340.1, D33.1 (K), J24.18 (+5V), R202.1, R203.1
+5VSB: C133.1, C134.1, C135.1, C345.2, C353.1, J1.9 (+5VSB), J16.9, J17.2, J19.U1 (VBUS), J19.U10 (VBUS), J21.1 (VBUS1), J21.10 (VBUS2), J22.1 (VBUS1), J22.11 (VBUS2), J23.1, J23.2, R92.1, U6.2 (VIN), U40.11 (PP_HV1), U40.12 (PP_HV1), U40.25 (PP_CABLE)
+12V: C2.1, C37.1, C60.1, C83.1, C108.1, C155.1, C156.1, C157.1, C158.1, C161.1, C162.1, C163.1, C164.1, C167.1, C168.1, C169.1, C170.1, D2.1 (K), D6.1 (K), D10.1 (K), D14.1 (K), D18.1 (K), J1.10 (+12V), J1.11 (+12V), J8.A2 (+12V), J8.A3 (+12V), J8.B1 (+12V), J8.B2 (+12V), J8.B3 (+12V), J9.A2 (+12V), J9.A3 (+12V), J9.B1 (+12V), J9.B2 (+12V), J9.B3 (+12V), J10.A2 (+12V), J10.A3 (+12V), J10.B1 (+12V), J10.B2 (+12V), J10.B3 (+12V), M2.2 (+), M4.2 (+), M6.2 (+), M8.2 (+), M10.2 (+), R2.1, R26.1, R42.1, R59.1, R76.1
+12VCPU: A1.250 (VIN), A1.251 (VIN), A1.252 (VIN), A1.253 (VIN), A1.254 (VIN), A1.255 (VIN), A1.256 (VIN), A1.257 (VIN), A1.258 (VIN), A1.259 (VIN), A1.260 (VIN), A2.250 (VIN), A2.251 (VIN), A2.252 (VIN), A2.253 (VIN), A2.254 (VIN), A2.255 (VIN), A2.256 (VIN), A2.257 (VIN), A2.258 (VIN), A2.259 (VIN), A2.260 (VIN), A3.250 (VIN), A3.251 (VIN), A3.252 (VIN), A3.253 (VIN), A3.254 (VIN), A3.255 (VIN), A3.256 (VIN), A3.257 (VIN), A3.258 (VIN), A3.259 (VIN), A3.260 (VIN), A4.250 (VIN), A4.251 (VIN), A4.252 (VIN), A4.253 (VIN), A4.254 (VIN), A4.255 (VIN), A4.256 (VIN), A4.257 (VIN), A4.258 (VIN), A4.259 (VIN), A4.260 (VIN), A5.250 (VIN), A5.251 (VIN), A5.252 (VIN), A5.253 (VIN), A5.254 (VIN), A5.255 (VIN), A5.256 (VIN), A5.257 (VIN), A5.258 (VIN), A5.259 (VIN), A5.260 (VIN), C344.1, J2.5, J2.6, J2.7, J2.8, U40.1 (PP_HV2), U40.2 (PP_HV2)
+BATT: BT1.1 (+), R8.1, R32.1, R48.1, R65.1, R82.1
/HDMI/SLOT1_HDMI.HPD: A1.183 (DDIB_HPD), Q3.2 (S), R204.2
/HDMI/SLOT1_HDMI.SCL: A1.171 (DDIB_DDC_SCL), Q1.2 (S), R206.2
/HDMI/SLOT1_HDMI.SDA: A1.169 (DDIB_DDC_SDA), Q2.2 (S), R205.2
/HDMI/SLOT1_HDMI.Tx0+: A1.217 (DDIB_TX0+), C333.1
/HDMI/SLOT1_HDMI.Tx0-: A1.215 (DDIB_TX0-), C334.1
/HDMI/SLOT1_HDMI.Tx1+: A1.211 (DDIB_TX1+), C335.1
/HDMI/SLOT1_HDMI.Tx1-: A1.209 (DDIB_TX1-), C336.1
/HDMI/SLOT1_HDMI.Tx2+: A1.205 (DDIB_TX2+), C337.1
/HDMI/SLOT1_HDMI.Tx2-: A1.203 (DDIB_TX2-), C338.1
/HDMI/SLOT1_HDMI.Tx3+: A1.199 (DDIB_TX3+), C339.1
/HDMI/SLOT1_HDMI.Tx3-: A1.197 (DDIB_TX3-), C341.1
/Module 1/ETH.REFCLK+: A1.88 (REFCLK3+), U12.21 (PE_CLK_P)
/Module 1/ETH.REFCLK-: A1.90 (REFCLK3-), U12.22 (PE_CLK_N)
/Module 1/ETH.Rx0+: A1.64 (HSIO6_RX+), C241.1
/Module 1/ETH.Rx0-: A1.66 (HSIO6_RX-), C242.1
/Module 1/ETH.SMBCLK: A1.106 (SMB_CLK), U12.11 (SMB_CLK)
/Module 1/ETH.SMBDAT: A1.108 (SMB_DATA), U12.4 (ULP_WAKE_N), U12.10 (SMB_DATA)
/Module 1/ETH.Tx0+: C21.1, U12.28 (PE_Rx_P)
/Module 1/ETH.Tx0-: C22.1, U12.27 (PE_Rx_N)
/Module 1/ETH.~CLKREQ: A1.100 (~CLKREQ3), U12.3 (PE_CLKREQ_N)
/Module 1/HDD_LED: A1.123 (GPP_B14), D4.1 (K), J16.3
/Module 1/M2_EKEY.REFCLK+: A1.94 (REFCLK4+), J7.47 (REFCLKp0)
/Module 1/M2_EKEY.REFCLK-: A1.96 (REFCLK4-), J7.49 (REFCLKn0)
/Module 1/M2_EKEY.Rx0+: A1.28 (HSIO2_RX+), J7.41 (PERp0)
/Module 1/M2_EKEY.Rx0-: A1.30 (HSIO2_RX-), J7.43 (PERn0)
/Module 1/M2_EKEY.Tx0+: C7.1, J7.35 (PETp0)
/Module 1/M2_EKEY.Tx0-: C8.1, J7.37 (PETn0)
/Module 1/NVME.REFCLK+: A1.97 (REFCLK2+), J11.55 (REFCLKp)
/Module 1/NVME.REFCLK-: A1.99 (REFCLK2-), J11.53 (REFCLKn)
/Module 1/NVME.Rx0+: A1.40 (HSIO8_RX+), J11.43 (PERp0/SATA-B-)
/Module 1/NVME.Rx0-: A1.42 (HSIO8_RX-), J11.41 (PERn0/SATA-B+)
/Module 1/NVME.Rx1+: A1.46 (HSIO9_RX+), J11.31 (PERp1)
/Module 1/NVME.Rx1-: A1.48 (HSIO9_RX-), J11.29 (PERn1)
/Module 1/NVME.SUSCLK: A1.131 (SUSCLK), J11.68 (SUSCLK)
/Module 1/NVME.Tx0+: C9.1, J11.49 (PETp0/SATA-A+)
/Module 1/NVME.Tx0-: C10.1, J11.47 (PETn0/SATA-A-)
/Module 1/NVME.Tx1+: C11.1, J11.37 (PETp1)
/Module 1/NVME.Tx1-: C12.1, J11.35 (PETn1)
/Module 1/NVME.~PLTRST: A1.105 (~PLTRST), J7.52 (~PERST0), J11.50 (~PERST), U12.13 (PE_RST_N)
/Module 1/NVME.~WAKE: A1.103 (~WAKE), J7.55 (~PEWAKE0), J11.54 (~PEWAKE), U12.12 (PE_WAKE_N)
/Module 1/PGM_INT: A1.132 (GPP_D2), U40.29 (I2C1_IRQ_N)
/Module 1/PGM_SCL: A1.154 (I2C2_SCL), U40.27 (I2C1_SCL)
/Module 1/PGM_SDA: A1.156 (I2C2_SDA), U40.28 (I2C1_SDA)
/Module 1/RUSB_1.D+: A1.69 (USB2_P1+), J19.U3 (D+), U28.2
/Module 1/RUSB_1.D-: A1.67 (USB2_P1-), J19.U2 (D-), U28.1
/Module 1/RUSB_1.SS_Rx1+: A1.16 (HSIO0_RX+), J19.U6 (SSRX+), U30.4
/Module 1/RUSB_1.SS_Rx1-: A1.18 (HSIO0_RX-), J19.U5 (SSRX-), U30.2
/Module 1/RUSB_1.SS_Tx1+: C3.1, J19.U9 (SSTX+), U30.5
/Module 1/RUSB_1.SS_Tx1-: C4.1, J19.U8 (SSTX-), U30.1
/Module 1/RUSB_2.D+: A1.75 (USB2_P2+), J19.U12 (D+), U28.4
/Module 1/RUSB_2.D-: A1.73 (USB2_P2-), J19.U11 (D-), U28.5
/Module 1/RUSB_2.SS_Rx1+: A1.22 (HSIO1_RX+), J19.U15 (SSRX+), U29.4
/Module 1/RUSB_2.SS_Rx1-: A1.24 (HSIO1_RX-), J19.U14 (SSRX-), U29.2
/Module 1/RUSB_2.SS_Tx1+: C5.1, J19.U18 (SSTX+), U29.5
/Module 1/RUSB_2.SS_Tx1-: C6.1, J19.U17 (SSTX-), U29.1
/Module 1/SATA1.Rx+: C15.1, J3.A2 (Rx0+)
/Module 1/SATA1.Rx-: C16.1, J3.A3 (Rx0-)
/Module 1/SATA1.Tx+: C13.1, J3.B2 (Tx0+)
/Module 1/SATA1.Tx-: C14.1, J3.B3 (Tx0-)
/Module 1/SATA2.Rx+: C19.1, J4.A2 (Rx0+)
/Module 1/SATA2.Rx-: C20.1, J4.A3 (Rx0-)
/Module 1/SATA2.Tx+: C17.1, J4.B2 (Tx0+)
/Module 1/SATA2.Tx-: C18.1, J4.B3 (Tx0-)
/Module 1/SLOT2_UART_RX: A2.139 (UART0_TXD), R11.1
/Module 1/SLOT2_UART_TX: A2.137 (UART0_RXD), R10.1
/Module 1/SLOT3_UART_RX: A3.139 (UART0_TXD), R13#2.2
/Module 1/SLOT3_UART_TX: A3.137 (UART0_RXD), R14.2
/Module 1/SLOT4_UART_RX: A4.139 (UART0_TXD), R15.2
/Module 1/SLOT4_UART_TX: A4.137 (UART0_RXD), R16.2
/Module 1/SLOT5_UART_RX: A5.139 (UART0_TXD), R17.2
/Module 1/SLOT5_UART_TX: A5.137 (UART0_RXD), R18.2
/Module 1/TYPE_C_HEADER.D+: A1.112 (USB2_P6+), J25.18 (D-), U41.4
/Module 1/TYPE_C_HEADER.D-: A1.114 (USB2_P6-), J25.19 (D+), U41.5
/Module 1/TYPE_C_HEADER.SBU2: C24.2, C26.1, C27.1, D37.2 (A2), D38.2 (A2), J25.9 (SBU1), J25.10 (SBU2), R23.1
/Module 1/TYPE_C_HEADER.SS_Rx1+: C32.1, J25.5 (RX1+), U42.5
/Module 1/TYPE_C_HEADER.SS_Rx1-: C33.1, J25.6 (RX1-), U42.4
/Module 1/TYPE_C_HEADER.SS_Rx2+: C28.1, J25.15 (RX2+), U44.1
/Module 1/TYPE_C_HEADER.SS_Rx2-: C29.1, J25.16 (RX2-), U44.2
/Module 1/TYPE_C_HEADER.SS_Tx1+: C34.1, J25.2 (TX1+), U42.1
/Module 1/TYPE_C_HEADER.SS_Tx1-: C35.1, J25.3 (TX1-), U42.2
/Module 1/TYPE_C_HEADER.SS_Tx2+: C30.1, J25.12 (TX2+), U44.5
/Module 1/TYPE_C_HEADER.SS_Tx2-: C31.1, J25.13 (TX2-), U44.4
/Module 1/TYPE_C_HPD: A1.185 (TCP1_HPD), R211.1, U40.30 (HPD(GPIO3))
/Module 1/TYPE_C_SCL: A1.147 (SML1_CLK), U40.32 (I2C2_SCL)
/Module 1/TYPE_C_SDA: A1.145 (SML1_DATA), U40.33 (I2C2_SDA)
/Module 1/~TYPE_C_PMCALERT: A1.125 (GPP_B11), U40.34 (I2C2_IRQ_N)
/Module 2/ETH.REFCLK+: A2.88 (REFCLK3+), U13.21 (PE_CLK_P)
/Module 2/ETH.REFCLK-: A2.90 (REFCLK3-), U13.22 (PE_CLK_N)
/Module 2/ETH.Rx0+: A2.64 (HSIO6_RX+), C243.1
/Module 2/ETH.Rx0-: A2.66 (HSIO6_RX-), C244.1
/Module 2/ETH.SMBCLK: A2.147 (SML1_CLK), U13.11 (SMB_CLK)
/Module 2/ETH.SMBDAT: A2.145 (SML1_DATA), U13.4 (ULP_WAKE_N), U13.10 (SMB_DATA)
/Module 2/ETH.Tx0+: C56.1, U13.28 (PE_Rx_P)
/Module 2/ETH.Tx0-: C57.1, U13.27 (PE_Rx_N)
/Module 2/ETH.~CLKREQ: A2.100 (~CLKREQ3), U13.3 (PE_CLKREQ_N)
/Module 2/FUSB.D+: A2.75 (USB2_P2+), J22.3 (D1+), U34.2
/Module 2/FUSB.D-: A2.73 (USB2_P2-), J22.2 (D1-), U34.1
/Module 2/FUSB.SS_Rx1+: A2.22 (HSIO1_RX+), J22.6 (SSRX1+), U36.4
/Module 2/FUSB.SS_Rx1-: A2.24 (HSIO1_RX-), J22.5 (SSRX1-), U36.2
/Module 2/FUSB.SS_Tx1+: C40.1, J22.9 (SSTX1+), U36.5
/Module 2/FUSB.SS_Tx1-: C41.1, J22.8 (SSTX1-), U36.1
/Module 2/M2_EKEY.REFCLK+: A2.94 (REFCLK4+), J6.47 (REFCLKp0)
/Module 2/M2_EKEY.REFCLK-: A2.96 (REFCLK4-), J6.49 (REFCLKn0)
/Module 2/M2_EKEY.Rx0+: A2.28 (HSIO2_RX+), J6.41 (PERp0)
/Module 2/M2_EKEY.Rx0-: A2.30 (HSIO2_RX-), J6.43 (PERn0)
/Module 2/M2_EKEY.Tx0+: C42.1, J6.35 (PETp0)
/Module 2/M2_EKEY.Tx0-: C43.1, J6.37 (PETn0)
/Module 2/M2_EKEY.USB-D+: A2.81 (USB2_P3+), J6.3 (USB_D+)
/Module 2/M2_EKEY.USB-D-: A2.79 (USB2_P3-), J6.5 (USB_D-)
/Module 2/NVME.REFCLK+: A2.97 (REFCLK2+), J12.55 (REFCLKp)
/Module 2/NVME.REFCLK-: A2.99 (REFCLK2-), J12.53 (REFCLKn)
/Module 2/NVME.Rx0+: A2.40 (HSIO8_RX+), J12.43 (PERp0/SATA-B-)
/Module 2/NVME.Rx0-: A2.42 (HSIO8_RX-), J12.41 (PERn0/SATA-B+)
/Module 2/NVME.Rx1+: A2.46 (HSIO9_RX+), J12.31 (PERp1)
/Module 2/NVME.Rx1-: A2.48 (HSIO9_RX-), J12.29 (PERn1)
/Module 2/NVME.SUSCLK: A2.131 (SUSCLK), J6.50 (SUSCLK), J12.68 (SUSCLK)
/Module 2/NVME.Tx0+: C44.1, J12.49 (PETp0/SATA-A+)
/Module 2/NVME.Tx0-: C45.1, J12.47 (PETn0/SATA-A-)
/Module 2/NVME.Tx1+: C46.1, J12.37 (PETp1)
/Module 2/NVME.Tx1-: C47.1, J12.35 (PETn1)
/Module 2/NVME.~PLTRST: A2.105 (~PLTRST), J6.52 (~PERST0), J12.50 (~PERST), U13.13 (PE_RST_N)
/Module 2/NVME.~WAKE: A2.103 (~WAKE), J6.55 (~PEWAKE0), J12.54 (~PEWAKE), U13.12 (PE_WAKE_N)
/Module 2/RUSB.D+: A2.69 (USB2_P1+), J21.3 (D1+), U31.2
/Module 2/RUSB.D-: A2.67 (USB2_P1-), J21.2 (D1-), U31.1
/Module 2/RUSB.SS_Rx1+: A2.16 (HSIO0_RX+), J21.6 (SSRX1+), U33.4
/Module 2/RUSB.SS_Rx1-: A2.18 (HSIO0_RX-), J21.5 (SSRX1-), U33.2
/Module 2/RUSB.SS_Tx1+: C38.1, J21.9 (SSTX1+), U33.5
/Module 2/RUSB.SS_Tx1-: C39.1, J21.8 (SSTX1-), U33.1
/Module 2/SATA1.Rx+: C50.1, J3.A5 (Rx1+)
/Module 2/SATA1.Rx-: C51.1, J3.A6 (Rx1-)
/Module 2/SATA1.Tx+: C48.1, J3.B5 (Tx1+)
/Module 2/SATA1.Tx-: C49.1, J3.B6 (Tx1-)
/Module 2/SATA2.Rx+: C54.1, J4.A5 (Rx1+)
/Module 2/SATA2.Rx-: C55.1, J4.A6 (Rx1-)
/Module 2/SATA2.Tx+: C52.1, J4.B5 (Tx1+)
/Module 2/SATA2.Tx-: C53.1, J4.B6 (Tx1-)
/Module 3/ETH.REFCLK+: A3.88 (REFCLK3+), U20.21 (PE_CLK_P)
/Module 3/ETH.REFCLK-: A3.90 (REFCLK3-), U20.22 (PE_CLK_N)
/Module 3/ETH.Rx0+: A3.64 (HSIO6_RX+), C293.1
/Module 3/ETH.Rx0-: A3.66 (HSIO6_RX-), C294.1
/Module 3/ETH.SMBCLK: A3.106 (SMB_CLK), U20.11 (SMB_CLK)
/Module 3/ETH.SMBDAT: A3.108 (SMB_DATA), U20.4 (ULP_WAKE_N), U20.10 (SMB_DATA)
/Module 3/ETH.Tx0+: C79.1, U20.28 (PE_Rx_P)
/Module 3/ETH.Tx0-: C80.1, U20.27 (PE_Rx_N)
/Module 3/ETH.~CLKREQ: A3.100 (~CLKREQ3), U20.3 (PE_CLKREQ_N)
/Module 3/FUSB.D+: A3.75 (USB2_P2+), J22.13 (D2+), U34.4
/Module 3/FUSB.D-: A3.73 (USB2_P2-), J22.12 (D2-), U34.5
/Module 3/FUSB.SS_Rx1+: A3.22 (HSIO1_RX+), J22.16 (SSRX2+), U35.4
/Module 3/FUSB.SS_Rx1-: A3.24 (HSIO1_RX-), J22.15 (SSRX2-), U35.2
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

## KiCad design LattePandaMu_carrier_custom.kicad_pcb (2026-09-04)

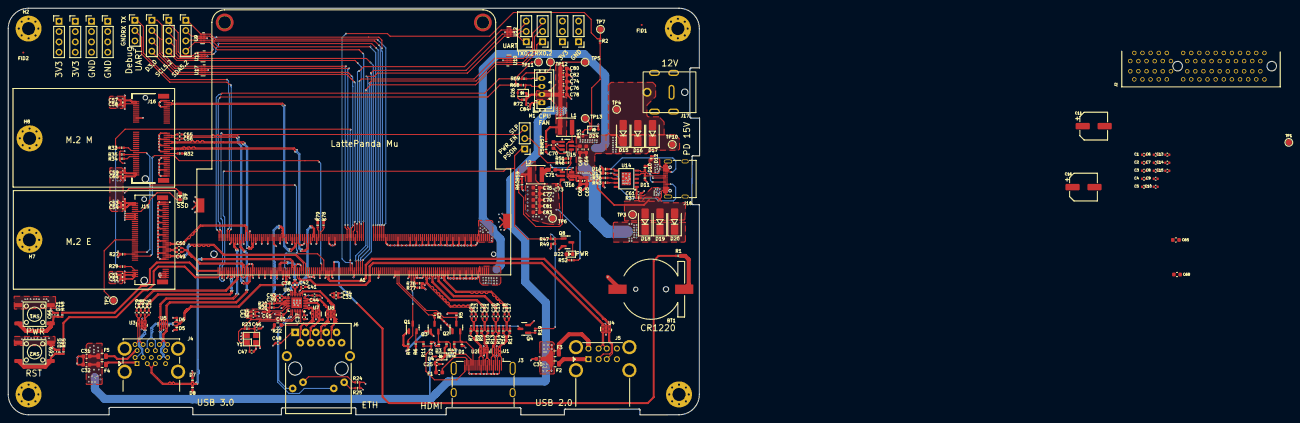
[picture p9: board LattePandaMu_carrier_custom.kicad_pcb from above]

Board: 4 copper layers, 170.1 x 100.0 mm, 236 parts (0 on the bottom side), 198 nets.

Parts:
A1: LattePanda_Mu; LattePanda_Module_H8.0mm_Horizontal
BT1: Battery_Cell; Battery_Holder_CR1220_S8411-45R
C1, C2, C3, C4, C5, C6, C7, C8, C49, C50, C55, C56: 220nF/50V; C_0402_1005Metric
C9, C10, C13, C15, C17, C18, C19, C20, C21, C22, C23, C24, C25, C26, C27, C28, C29, C33, C34, C35, C36, C37, C38, C39, C40, C41, C42, C43, C45, C48, C52, C54, C58, C60, C84: 100nF/50V; C_0402_1005Metric
C11: 100uF/25V; CP_Elec_6.3x7.7
C14: 10uF/10V; C_0402_1005Metric
C16: 560uF/25V; CP_Elec_6.3x7.7
C30, C31, C32, C64, C65, C65#2, C67, C68, C68#2, C74, C75, C76, C77, C80, C81, C82, C83: 22uF/10V; C_0603_1608Metric
C44, C51, C53, C57, C59: 10uF/50V; C_0402_1005Metric
C46, C47, C73: 12pF/50V; C_0402_1005Metric
C61, C66, C69: 1uF/16V; C_0402_1005Metric
C70, C71: 100nF/50V; C_0603_1608Metric
C78, C79: 100nF/10V; C_0603_1608Metric
D1, D2, D3: ESD5V0B03; D_0402_1005Metric
D4, D26: 1N5819WS; D_SOD-323
D5, D6, D7, D8, D10, D11, D21, D25: ESD9B5.0ST5G; D_0402_1005Metric
D9: LED_G; LED_0603_1608Metric
D12, D13, D14: D_Zener; D_0402_1005Metric
D15, D16, D17, D18, D19, D20: D_Schottky; D_SMA
D22: LED; LED_0603_1608Metric
D24: 3V3 Izt=5mA; D_SOD-323
F1: 6V/50mA; C_0603_1608Metric
F2, F3, F4, F5: 6V/1A; Fuse_0805_2012Metric
FID1, FID2: Fiducial; Fiducial_0.5mm_Mask1mm
H1, H2, H3, H4, H7, H8: MountingHole_Pad; MountingHole_3.2mm_M3_Pad_Via
H5, H6: MountingHole_Pad; MountingHole_3mm_M2_Pad_TopOnly
J1, J8, J10, J11, J14: Conn_01x03_Pin; PinHeader_1x03_P2.54mm_Vertical
J2: Bus_PCI_Express_x4; PCIe_x4_Gen3Slot_Connectors
J3: HDMI_A; HDMI_A_Molex_208658-1001_Horizontal
J4: USB3_A_Stacked; USB3_A_Molex_48406-0001_Horizontal_Stacked
J5: USB_A_Stacked; USB_A_CUI_UJ2-ADH-TH_Horizontal_Stacked
J6: RJ45_RB1-125B8G1A; RJ45_UDE_RB1-125B8G1A
J7, J9, J12, J13, J19, J20, J21: Conn_01x04_Pin; PinHeader_1x04_P2.54mm_Vertical
J15: Bus_M.2_Socket_M; PCIe_M.2_Connectors_P=0.5mm_H=4.2mm_KeyM
J16: Bus_M.2_Socket_E; PCIe_M.2_Connectors_P=0.5mm_H=4.2mm_KeyE
J17: Barrel_Jack_Switch; DC_Jack_DC007B_30V_10A
J18: USB_C_Receptacle_USB2.0_16P; USB_C_Receptacle_G-Switch_GT-USB-7010ASV
JP1: Jumper_3_Bridged12; PinHeader_1x03_P2.54mm_Vertical
L1, L2: 2.2uH/4.3A; L_Sunlord_SWPA4020S
M1: Fan_4pin; JST_PH_B4B-PH-K_1x04_P2.00mm_Vertical
Q1, Q8: 2N7002; SOT-23
Q2, Q3, Q4: 2SK3018; SOT-23
R1, R11, R37, R47: 1K/1%; R_0402_1005Metric
R2, R20, R21, R34, R35, R36, R49, R58, R78, R79: 10K/1%; R_0402_1005Metric
R3, R5, R15, R18, R19, R52, R53: 2.2K/1%; R_0402_1005Metric
R4, R23: 1M/1%; R_0402_1005Metric
R6, R59, R68: 21.5K/1%; R_0402_1005Metric
R7, R8, R9, R10, R13, R14, R16, R17, R24, R25: 470R/1%; R_0402_1005Metric
R22: 2.49K/1%; R_0603_1608Metric
R27, R29, R32, R33: 0R/1%; R_0402_1005Metric
R43: 56K/1%; R_0402_1005Metric
R46, R51, R76, R77: 100K/1%; R_0402_1005Metric
R48, R55, R69: 100R/1%; R_0402_1005Metric
R57: 75K/1%; R_0402_1005Metric
R60, R72: 4.7K/1%; R_0402_1005Metric
SW1, SW2: SW_Push; SW_Push_6x6x6
TP1, TP2, TP3, TP4, TP5, TP6, TP7, TP10, TP11, TP12, TP13: TestPoint; TestPoint_Pad_D1.5mm
U1, U2, U3, U4, U5, U7, U8: D3V3XA4B10LP; Diodes_UDFN-10_1.0x2.5mm_P0.5mm
U6: RTL8111H-CG-RH; QFN-32-1EP_4x4mm_P0.4mm_EP2.65x2.65mm
U9, U10, U11, U12, U17: ULC0524P; Diodes_UDFN-10_1.0x2.5mm_P0.5mm
U14: USB PD等快充协议受电芯片-CH224K-ESSOP10; ESSOP-10-1EP_3.9x5mm_P1.0mm_EP3.2x2.3
U15, U16: LM2734X; TSOT-23-6
Y1: 25MHz; Crystal_SMD_3225-4Pin_3.2x2.5mm

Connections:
5V_HDMI_VCC: C25.1, D4.1 (K), F1.1, R15.1, R18.1
+1V0: C33.2, C34.2, C35.2, C36.2, C40.2, C44.2, U6.3 (AVDD10), U6.8 (AVDD10), U6.22 (DVDD10), U6.24 (REGOUT), U6.30 (AVDD10)
+3V3: C13.2, C14.2, C15.1, C16.1, C37.2, C41.2, C45.2, C51.2, C52.2, C53.2, C54.2, C57.2, C58.2, C59.2, C60.2, C73.1, C75.1, C77.1, C79.1, C81.1, C83.1, D9.2 (A), J2.A9 (+3.3V), J2.A10 (+3.3V), J2.B8 (+3.3V), J2.B10 (3.3Vaux), J13.1, J13.2, J13.3, J13.4, J14.1, J14.2, J14.3, J15.2 (3.3V), J15.4 (3.3V), J15.12 (3.3V), J15.14 (3.3V), J15.16 (3.3V), J15.18 (3.3V), J15.70 (3.3V), J15.72 (3.3V), J15.74 (3.3V), J16.2 (3.3V), J16.4 (3.3V), J16.72 (3.3V), J16.74 (3.3V), J21.1, J21.2, J21.3, J21.4, L2.2, Q1.1 (G), Q2.1 (G), Q3.1 (G), R3.1, R4.1, R5.1, R20.2, R21.2, R24.2, R25.2, R34.2, R35.2, R52.1, R59.2, TP6.1 (1_1), U6.11 (AVDD33), U6.23 (VDDREG), U6.32 (AVDD33)
+5V: C30.2, C31.2, C32.2, C74.1, C76.1, C78.1, C80.1, C82.1, C84.1, D4.2 (A), D26.1 (K), F2.1, F3.1, F4.1, F5.1, L1.2, M1.2 (+), R57.2, R72.1, TP5.1 (1_1)
+12V: D15.2 (A), D16.2 (A), D17.2 (A), J17.1, TP4.1 (1_1)
+12VA: C9.1, C10.1, C11.1, J2.A2 (+12V), J2.A3 (+12V), J2.B1 (+12V), J2.B2 (+12V), J2.B3 (+12V)
+15V: D12.1 (K), D18.2 (A), D19.2 (A), D20.2 (A), J18.A4 (VBUS), J18.A9 (VBUS), J18.B4 (VBUS), J18.B9 (VBUS), R36.1, R37.1, TP3.1 (1_1)
+BATT: A1.115 (VBAT), R1.2
/Fan/FAN_1_PWM: A1.2 (FAN1_PWM), R69.1, TP12.1 (1_1)
/Fan/FAN_1_TAC: A1.4 (FAN1_TAC), R68.1, TP11.1 (1_1)
/GPIO/GPP_D0: A1.128 (GPP_D0), J19.1, U17.1, U17.10 (NC)
/GPIO/GPP_D1: A1.130 (GPP_D1), J19.2, U17.2, U17.9 (NC)
/GPIO/GPP_D2: A1.132 (GPP_D2), J19.3, U17.4, U17.7 (NC)
/GPIO/GPP_D3: A1.134 (GPP_D3), J19.4, U17.5, U17.6 (NC)
/GPIO/I2C2_SCL: A1.154 (I2C2_SCL), J9.1, U11.1, U11.10 (NC)
/GPIO/I2C2_SDA: A1.156 (I2C2_SDA), J7.1, U9.1, U9.10 (NC)
/GPIO/I2C3_SCL: A1.150 (I2C3_SCL), J9.2, U11.2, U11.9 (NC)
/GPIO/I2C3_SDA: A1.152 (I2C3_SDA), J7.2, U9.2, U9.9 (NC)
/GPIO/I2C4_SCL: A1.146 (I2C4_SCL), J9.3, U11.4, U11.7 (NC)
/GPIO/I2C4_SDA: A1.148 (I2C4_SDA), J7.3, U9.4, U9.7 (NC)
/GPIO/I2C5_SCL: A1.142 (I2C5_SCL), J9.4, U11.5, U11.6 (NC)
/GPIO/I2C5_SDA: A1.144 (I2C5_SDA), J7.4, U9.5, U9.6 (NC)
/GPIO/SOC_UART0_RX: A1.137 (UART0_RXD), J8.1, U10.1, U10.10 (NC)
/GPIO/SOC_UART0_TX: A1.139 (UART0_TXD), J10.1, U12.1, U12.10 (NC)
/GPIO/SOC_UART1_RX: A1.141 (UART1_RXD), J8.2, U10.2, U10.9 (NC)
/GPIO/SOC_UART1_TX: A1.143 (UART1_TXD), J10.2, U12.2, U12.9 (NC)
/GPIO/SOC_UART2_RX: A1.140 (UART2_RXD), J8.3, U10.4, U10.7 (NC)
/GPIO/SOC_UART2_TX: A1.138 (UART2_TXD), J10.3, U12.4, U12.7 (NC)
/Gigabit Ethernet/GbE_PCIe_CLK+: A1.94 (REFCLK4+), U6.15 (REFCLK_P)
/Gigabit Ethernet/GbE_PCIe_CLK-: A1.96 (REFCLK4-), U6.16 (REFCLK_N)
/Gigabit Ethernet/GbE_PCIe_RX+: A1.64 (HSIO6_RX+), C43.2
/Gigabit Ethernet/GbE_PCIe_RX-: A1.66 (HSIO6_RX-), C39.2
/Gigabit Ethernet/GbE_PCIe_TX+: A1.61 (HSIO6_TX+), C42.2
/Gigabit Ethernet/GbE_PCIe_TX-: A1.63 (HSIO6_TX-), C38.2
/Gigabit Ethernet/HSI+: C42.1, U6.13 (HSIP)
/Gigabit Ethernet/HSI-: C38.1, U6.14 (HSIN)
/Gigabit Ethernet/HSO+: C43.1, U6.17 (HSOP)
/Gigabit Ethernet/HSO-: C39.1, U6.18 (HSON)
/Gigabit Ethernet/MDI0+: J6.R2 (TD1+), U6.1 (MDIP0), U7.1, U7.10 (NC)
/Gigabit Ethernet/MDI0-: J6.R3 (TD1-), U6.2 (MDIN0), U7.2, U7.9 (NC)
/Gigabit Ethernet/MDI1+: J6.R4 (TD2+), U6.4 (MDIP1), U7.4, U7.7 (NC)
/Gigabit Ethernet/MDI1-: J6.R5 (TD2-), U6.5 (MDIN1), U7.5, U7.6 (NC)
/Gigabit Ethernet/MDI2+: J6.R6 (TD3+), U6.6 (MDIP2), U8.5, U8.6 (NC)
/Gigabit Ethernet/MDI2-: J6.R7 (TD3-), U6.7 (MDIN2), U8.4, U8.7 (NC)
/Gigabit Ethernet/MDI3+: J6.R8 (TD4+), U6.9 (MDIP3), U8.2, U8.9 (NC)
/Gigabit Ethernet/MDI3-: J6.R9 (TD4-), U6.10 (MDIN3), U8.1, U8.10 (NC)
/HDMI/DDC_SCL: D1.2 (A2), J3.15 (SCL), Q2.2 (S), R15.2
/HDMI/DDC_SDA: D3.2 (A2), J3.16 (SDA), Q3.2 (S), R18.2
/HDMI/DDI_B_DDC_SCL: A1.171 (DDIB_DDC_SCL), Q2.3 (D), R5.2
/HDMI/DDI_B_DDC_SDA: A1.169 (DDIB_DDC_SDA), Q3.3 (D), R3.2
/HDMI/DDI_B_HPD: A1.183 (DDIB_HPD), Q1.3 (D), R4.2
/HDMI/DDI_B_TX0+: A1.217 (DDIB_TX0+), C17.1
/HDMI/DDI_B_TX0-: A1.215 (DDIB_TX0-), C18.1
/HDMI/DDI_B_TX1+: A1.211 (DDIB_TX1+), C19.1
/HDMI/DDI_B_TX1-: A1.209 (DDIB_TX1-), C20.1
/HDMI/DDI_B_TX2+: A1.205 (DDIB_TX2+), C21.1
/HDMI/DDI_B_TX2-: A1.203 (DDIB_TX2-), C22.1
/HDMI/DDI_B_TX3+: A1.199 (DDIB_TX3+), C23.1
/HDMI/DDI_B_TX3-: A1.197 (DDIB_TX3-), C24.1
/HDMI/HPD: D2.2 (A2), J3.19 (HPD), R11.2
/HDMI/TMDS_CK+: C23.2, J3.10 (CK+), R8.2, U2.4, U2.7 (NC)
/HDMI/TMDS_CK-: C24.2, J3.12 (CK-), R7.2, U2.5, U2.6 (NC)
/HDMI/TMDS_D0+: C21.2, J3.7 (D0+), R10.2, U2.1, U2.10 (NC)
/HDMI/TMDS_D0-: C22.2, J3.9 (D0-), R9.2, U2.2, U2.9 (NC)
/HDMI/TMDS_D1+: C19.2, J3.4 (D1+), R14.2, U1.4, U1.7 (NC)
/HDMI/TMDS_D1-: C20.2, J3.6 (D1-), R13.2, U1.5, U1.6 (NC)
/HDMI/TMDS_D2+: C17.2, J3.1 (D2+), R17.2, U1.1, U1.10 (NC)
/HDMI/TMDS_D2-: C18.2, J3.3 (D2-), R16.2, U1.2, U1.9 (NC)
/LattePanda Module/HSIO_0_TX+: A1.13 (HSIO0_TX+), C27.1
/LattePanda Module/HSIO_0_TX-: A1.15 (HSIO0_TX-), C26.1
/LattePanda Module/HSIO_1_TX+: A1.19 (HSIO1_TX+), C29.1
/LattePanda Module/HSIO_1_TX-: A1.21 (HSIO1_TX-), C28.1
/LattePanda Module/HSIO_2_RX+: A1.28 (HSIO2_RX+), J15.43 (PERp0/SATA-B-)
/LattePanda Module/HSIO_2_RX-: A1.30 (HSIO2_RX-), J15.41 (PERn0/SATA-B+)
/LattePanda Module/HSIO_2_TX+: A1.25 (HSIO2_TX+), C49.1
/LattePanda Module/HSIO_2_TX-: A1.27 (HSIO2_TX-), C50.1
/LattePanda Module/HSIO_3_RX+: A1.34 (HSIO3_RX+), J16.41 (PERp0)
/LattePanda Module/HSIO_3_RX-: A1.36 (HSIO3_RX-), J16.43 (PERn0)
/LattePanda Module/HSIO_3_TX+: A1.31 (HSIO3_TX+), C55.1
/LattePanda Module/HSIO_3_TX-: A1.33 (HSIO3_TX-), C56.1
/LattePanda Module/HSIO_8_RX+: A1.40 (HSIO8_RX+), J2.A16 (PERp0)
/LattePanda Module/HSIO_8_RX-: A1.42 (HSIO8_RX-), J2.A17 (PERn0)
/LattePanda Module/HSIO_8_TX+: A1.37 (HSIO8_TX+), C1.1
/LattePanda Module/HSIO_8_TX-: A1.39 (HSIO8_TX-), C2.1
/LattePanda Module/HSIO_9_RX+: A1.46 (HSIO9_RX+), J2.A21 (PERp1)
/LattePanda Module/HSIO_9_RX-: A1.48 (HSIO9_RX-), J2.A22 (PERn1)
/LattePanda Module/HSIO_9_TX+: A1.43 (HSIO9_TX+), C3.1
/LattePanda Module/HSIO_9_TX-: A1.45 (HSIO9_TX-), C4.1
/LattePanda Module/HSIO_10_RX+: A1.52 (HSIO10_RX+), J2.A25 (PERp2)
/LattePanda Module/HSIO_10_RX-: A1.54 (HSIO10_RX-), J2.A26 (PERn2)
/LattePanda Module/HSIO_10_TX+: A1.49 (HSIO10_TX+), C5.1
/LattePanda Module/HSIO_10_TX-: A1.51 (HSIO10_TX-), C6.1
/LattePanda Module/HSIO_11_RX+: A1.58 (HSIO11_RX+), J2.A29 (PERp3)
/LattePanda Module/HSIO_11_RX-: A1.60 (HSIO11_RX-), J2.A30 (PERn3)
/LattePanda Module/HSIO_11_TX+: A1.55 (HSIO11_TX+), C7.1
/LattePanda Module/HSIO_11_TX-: A1.57 (HSIO11_TX-), C8.1
/LattePanda Module/REFCLK0+: A1.85 (REFCLK0+), J15.55 (REFCLKp)
/LattePanda Module/REFCLK0-: A1.87 (REFCLK0-), J15.53 (REFCLKn)
/LattePanda Module/REFCLK2+: A1.97 (REFCLK2+), J2.A13 (REFCLK+)
/LattePanda Module/REFCLK2-: A1.99 (REFCLK2-), J2.A14 (REFCLK-)
/LattePanda Module/REFCLK3+: A1.88 (REFCLK3+), J16.47 (REFCLKp0)
/LattePanda Module/REFCLK3-: A1.90 (REFCLK3-), J16.49 (REFCLKn0)
/LattePanda Module/SUSCKL_WIFI: A1.131 (SUSCLK), R29.1, R33.2
/LattePanda Module/USB_2_P7+: A1.76 (USB2_P7+), J16.3 (USB_D+)
/LattePanda Module/USB_2_P7-: A1.78 (USB2_P7-), J16.5 (USB_D-)
/LattePanda Module/~PWR_SW: A1.1 (~PWRBTN), R48.1
/LattePanda Module/~RST_SW: A1.3 (~RSTBTN), R55.1
/M.2 M Key/CON_PCIE_TX0+: C55.2, J16.35 (PETp0)
/M.2 M Key/CON_PCIE_TX0-: C56.2, J16.37 (PETn0)
/M.2 M Key/CON_PCIE_TX1+: C49.2, J15.49 (PETp0/SATA-A+)
/M.2 M Key/CON_PCIE_TX1-: C50.2, J15.47 (PETn0/SATA-A-)
/M.2 M Key/~CLKREQE: J16.53 (~CLKREQ0), R32.1
/M.2 M Key/~CLKREQM: J15.52 (~CLKREQ), R27.1
/PCIe x4/PCIE30_TX0_N: C2.2, J2.B15 (PETn0)
/PCIe x4/PCIE30_TX0_P: C1.2, J2.B14 (PETp0)
/PCIe x4/PCIE30_TX1_N: C4.2, J2.B20 (PETn1)
/PCIe x4/PCIE30_TX1_P: C3.2, J2.B19 (PETp1)
/PCIe x4/PCIE30_TX2_N: C6.2, J2.B24 (PETn2)
/PCIe x4/PCIE30_TX2_P: C5.2, J2.B23 (PETp2)
/PCIe x4/PCIE30_TX3_N: C8.2, J2.B28 (PETn3)
/PCIe x4/PCIE30_TX3_P: C7.2, J2.B27 (PETp3)
/Power Supply/CC1: D13.1 (K), J18.A5 (CC1), U14.7 (CC1)
/Power Supply/CC2: D14.1 (K), J18.B5 (CC2), U14.6 (CC2)
/Power Supply/PWR_C_D+: D11.2 (A2), J18.A6 (D+), J18.B6 (D+), U14.4 (DP)
/Power Supply/PWR_C_D-: D10.2 (A2), J18.A7 (D-), J18.B7 (D-), U14.5 (DM)
/Power Supply/PWR_EN: R46.1, R51.2, U15.4 (EN), U16.4 (EN)
/USB 2.0 & 3.0/CON_USB1_D_N: A1.109 (USB2_P5-), J5.2 (D1-), U4.2, U4.9 (NC)
/USB 2.0 & 3.0/CON_USB1_D_P: A1.111 (USB2_P5+), J5.3 (D1+), U4.1, U4.10 (NC)
/USB 2.0 & 3.0/CON_USB2_D_N: A1.79 (USB2_P3-), J5.6 (D2-), U4.5, U4.6 (NC)
/USB 2.0 & 3.0/CON_USB2_D_P: A1.81 (USB2_P3+), J5.7 (D2+), U4.4, U4.7 (NC)
/USB 2.0 & 3.0/CON_USB3_D_N: A1.73 (USB2_P2-), D8.1 (A1), J4.2 (D1-)
/USB 2.0 & 3.0/CON_USB3_D_P: A1.75 (USB2_P2+), D7.1 (A1), J4.3 (D1+)
/USB 2.0 & 3.0/CON_USB3_SSRX_N: A1.18 (HSIO0_RX-), J4.5 (SSRX1-), U5.4, U5.7 (NC)
/USB 2.0 & 3.0/CON_USB3_SSRX_P: A1.16 (HSIO0_RX+), J4.6 (SSRX1+), U5.5, U5.6 (NC)
/USB 2.0 & 3.0/CON_USB3_SSTX_N: C26.2, J4.8 (SSTX1-), U3.1, U3.10 (NC)
/USB 2.0 & 3.0/CON_USB3_SSTX_P: C27.2, J4.9 (SSTX1+), U3.2, U3.9 (NC)
/USB 2.0 & 3.0/CON_USB4_D_N: A1.67 (USB2_P1-), D6.1 (A1), J4.11 (D2-)
/USB 2.0 & 3.0/CON_USB4_D_P: A1.69 (USB2_P1+), D5.1 (A1), J4.12 (D2+)
/USB 2.0 & 3.0/CON_USB4_SSRX_N: A1.24 (HSIO1_RX-), J4.14 (SSRX2-), U5.1, U5.10 (NC)
/USB 2.0 & 3.0/CON_USB4_SSRX_P: A1.22 (HSIO1_RX+), J4.15 (SSRX2+), U5.2, U5.9 (NC)
/USB 2.0 & 3.0/CON_USB4_SSTX_N: C28.2, J4.17 (SSTX2-), U3.4, U3.7 (NC)
/USB 2.0 & 3.0/CON_USB4_SSTX_P: C29.2, J4.18 (SSTX2+), U3.5, U3.6 (NC)
/~PLT_RST: A1.105 (~PLTRST), J2.A11 (~PERST), J15.50 (~PERST), J16.52 (~PERST0), TP1.1 (1_1), U6.19 (PERSTB)
/~PWR_LED/~PSON: A1.5 (SLS_S0), JP1.1 (A), R19.1, R47.2
/~WAKE: A1.103 (~WAKE), J2.B11 (~WAKE), J15.54 (~PEWAKE), J16.55 (~PEWAKE0)
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

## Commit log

2025-12-07 added vendor information
    [FIT0981_Active_cooler.STEP, GPIO.kicad_sch, Gigabit Ethernet.kicad_sch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]
2026-07-16 updated project
    [FIT0981_Active_cooler.STEP, GPIO.kicad_sch, Gigabit Ethernet.kicad_sch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]
2026-08-30 added reference design and finished routing
    [FIT0981_Active_cooler.STEP, GPIO.kicad_sch, Gigabit Ethernet.kicad_sch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]
2026-08-31 improved layout
    [LattePandaMu_carrier_custom.kicad_pcb]
2026-09-01 finished placement
    [LattePandaMu_carrier_custom-B_Cu.gbl, LattePandaMu_carrier_custom-B_Mask.gbs, LattePandaMu_carrier_custom-B_Paste.gbp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]
2026-09-04 added pcie to schematic
    [LattePandaMuCluster.kicad_pcb, LattePandaMuCluster.kicad_sch, LattePandaMu_carrier_custom.kicad_pcb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]
